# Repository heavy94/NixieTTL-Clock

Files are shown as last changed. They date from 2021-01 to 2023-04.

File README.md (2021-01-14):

# NixieTTL Clock
Tabletop digital clock built using TTL/CMOS logic ICs with a Nixie tube display.

**TODO**
- PCB layout and design.
- Test High Voltage power supply.
- Test need for base resistor on the cathode drivers.
- Test and tune blanking time generator.

**References**

This design is inspired by the following projects and resources:
- https://0x7d.com/2017/nixie-tube-clock/
- https://threeneurons.wordpress.com/nixie-power-supply/nixie-clock-kit-microcontroller/
- https://threeneurons.wordpress.com/nixie-power-supply/nixie-clock-kit-microcontroller/ghosting-due-to-transients/
- https://threeneurons.wordpress.com/nixie-power-supply/hv-supply-kit/

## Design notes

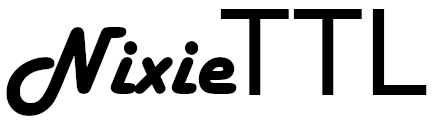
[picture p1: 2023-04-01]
NixieTTL.png

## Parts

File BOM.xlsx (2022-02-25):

Item | Qty | Reference(s) | Value | RS Reference | Mouser Reference | Datasheet
2 | 7 | C2, C3, C4, C5, C6, C7, C34 | 10n |  | 80-MMK5103J63J01TR18 | ~
3 | 19 | C8, C9, C10, C11, C12, C13, C14, C15, C16, C17, C18, C19, C20, C21, C22, C23, C24, C25, C26 | 100n |  | 80-R82DC3100AA50K | ~
4 | 2 | C27, C28 | 22p |  | 810-CC45SL3DD220JYGN | ~
5 | 1 | C29 | 22n |  |  | ~
6 | 1 | C30 | 10u 25V |  | 710-860020472003 (https://www.mouser.es/ProductDetail/710-860020472003) | ~
7 | 1 | C31 | 1u 16V |  | 710-860020672005 | ~
8 | 1 | C32 | 220u 25V |  | 710-860020474012 | ~
9 | 1 | C33 | 680p |  | 80-PFR5681J63J11L4 (https://www.mouser.es/ProductDetail/80-PFR5681J63J11L4) | ~
10 | 1 | C1, C35 | 3u3 250V |  | 710-860131174003 | ~
11 | 1 | D1 | 1N4001 |  | 625-1N4001-E3/54 | http://www.vishay.com/docs/88503/1n4001.pdf
12 | 1 | D2 | 1N914 |  | 78-1N914 | http://www.vishay.com/docs/85622/1n914.pdf
13 | 1 | D3 | MUR140 |  | 863-MUR140G | ~
14 | 1 | F1 | Fusible Clip |  | 693-0751.0062 | ~
15 | 2 | J1, J3 | Conn_02x02_Counter_Clockwise |  |  | https://www.mouser.es/Molex/Connectors/Headers-Wire-Housings/_/N-ay0loZ1yzvvqx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
16 | 2 | J2, J4 | Conn_02x09_Counter_Clockwise |  |  | ~
17 | 1 | J5 | Barrel_Jack |  | 163-179PH-EX | ~
18 | 1 | L1 | 560u 0,92A |  | 994-RFC1010B-564KE | ~
22 | 18 | Q1, Q2, Q3, Q4, Q5, Q6, Q7, Q8, Q9, Q10, Q11, Q12, Q15, Q16, Q17, Q18, Q21, Q22 | MPSA42 |  | 512-MPSA42 | http://www.onsemi.com/pub_link/Collateral/MPSA42-D.PDF
23 | 6 | Q13, Q14, Q19, Q20, Q23, Q24 | KSP92BU |  | 512-KSP92BU | http://www.onsemi.com/pub_link/Collateral/MPSA92-D.PDF
24 | 1 | Q25 | KSP2907A |  | 512-KSP2907ABU | ~
25 | 1 | Q26 | IRF644 |  | 844-IRF644PBF | ~
26 | 1 | R1 | 30k |  | 594-MBA0204BC3002FCT (https://www.mouser.es/ProductDetail/594-MBA0204BC3002FCT) | ~
28 | 25 | R2, R3, R4, R8, R9, R13, R14, R19, R20, R22, R24, R27, R28, R29, R30, R36, R38, R39, R40, R43, R45, R47, R48, R49, R50 | 220k |  | 603-MFR-25FTE52-220K | ~
29 | 11 | R5, R6, R10, R11, R15, R16, R25, R26, R31, R32, R59 | 1k24 1% |  | 603-MFR-25FBF52-1K24 | ~
30 | 12 | R7, R12, R17, R18, R33, R34, R41, R42, R53, R54, R55, R56 | 11k 1% |  | 603-MFR-25FBF52-11K | ~
33 | 1 | R51 | 4M7 |  | 594-VR25000004704JA1 | ~
34 | 1 | R52 | 20k |  |  | ~
35 | 2 | R57, R58 | 1.69 |  | 603-MFR-25FRF52-1R69 | ~
37 | 1 | R60 | 681k 1% |  | 603-MFR-25FBF52-681K (https://www.mouser.es/ProductDetail/603-MFR-25FBF52-681K) | ~
38 | 7 | R21, R23, R35, R37, R44, R46, R61 | 4k42 1% |  | 603-MFR-25FBF52-4K42 | ~
39 | 3 | SW1, SW2, SW3 | SW_Push |  | 642-MJTP1236D | ~
40 | 1 | SW4 | PB400EEQX |  | 612-PB400EEQX | ~
41 | 1 | U1 | 74LS14 | 14 | 595-SN74LS14N | http://www.ti.com/lit/gpn/sn74LS14
42 | 1 | U2 | 74LS109 | 16 | 595-SN74LS109AN | http://www.ti.com/lit/gpn/sn74LS109
43 | 1 | U3 | 74LS10 | 14 | 595-SN74LS10N | http://www.ti.com/lit/gpn/sn74LS10
44 | 2 | U4, U8 | 74LS08 | 14 | 595-SN74LS08N | http://www.ti.com/lit/gpn/sn74LS08
45 | 1 | U5 | 74LS393 | 14 | 595-SN74LS393N | 74xx\74LS393.pdf
46 | 1 | U6 | 74LS20 | 14 | 595-SN74LS20N | http://www.ti.com/lit/gpn/sn74LS20
47 | 1 | U7 | 74HC4060 | 16 | 595-SN74HC4060N | http://www.ti.com/lit/ds/symlink/dac5311.pdf
48 | 2 | U9, U13 | 4028 | 16 | 595-CD4028BE | http://www.intersil.com/content/dam/Intersil/documents/cd40/cd4028bms.pdf
49 | 4 | U10, U11, U12, U14 | 74LS151 | 16 | 595-SN74LS151N | http://www.ti.com/lit/gpn/sn74LS151
50 | 6 | U15, U16, U17, U18, U19, U20 | 74LS160 | 16 |  | http://www.ti.com/lit/gpn/sn74LS160
51 | 1 | U21 | L7805 |  | 511-L7805CV | http://www.st.com/content/ccc/resource/technical/document/datasheet/41/4f/b3/b0/12/d4/47/88/CD00000444.pdf/files/CD00000444.pdf/jcr:content/translations/en.CD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
52 | 1 | U22 | MC34063AP |  | 595-MC34063AP | http://www.onsemi.com/pub_link/Collateral/MC34063A-D.PDF
53 | 1 | Y1 | 32.768 kHz - 12.5pF |  | 449-LFXTAL002996BULK | ~
54 | 6 | Zocalo DIP14 |  |  | 649-DILB14P-223TLF
55 | 14 | Zocalo DIP16 |  |  | 649-DILB16P-223TLF

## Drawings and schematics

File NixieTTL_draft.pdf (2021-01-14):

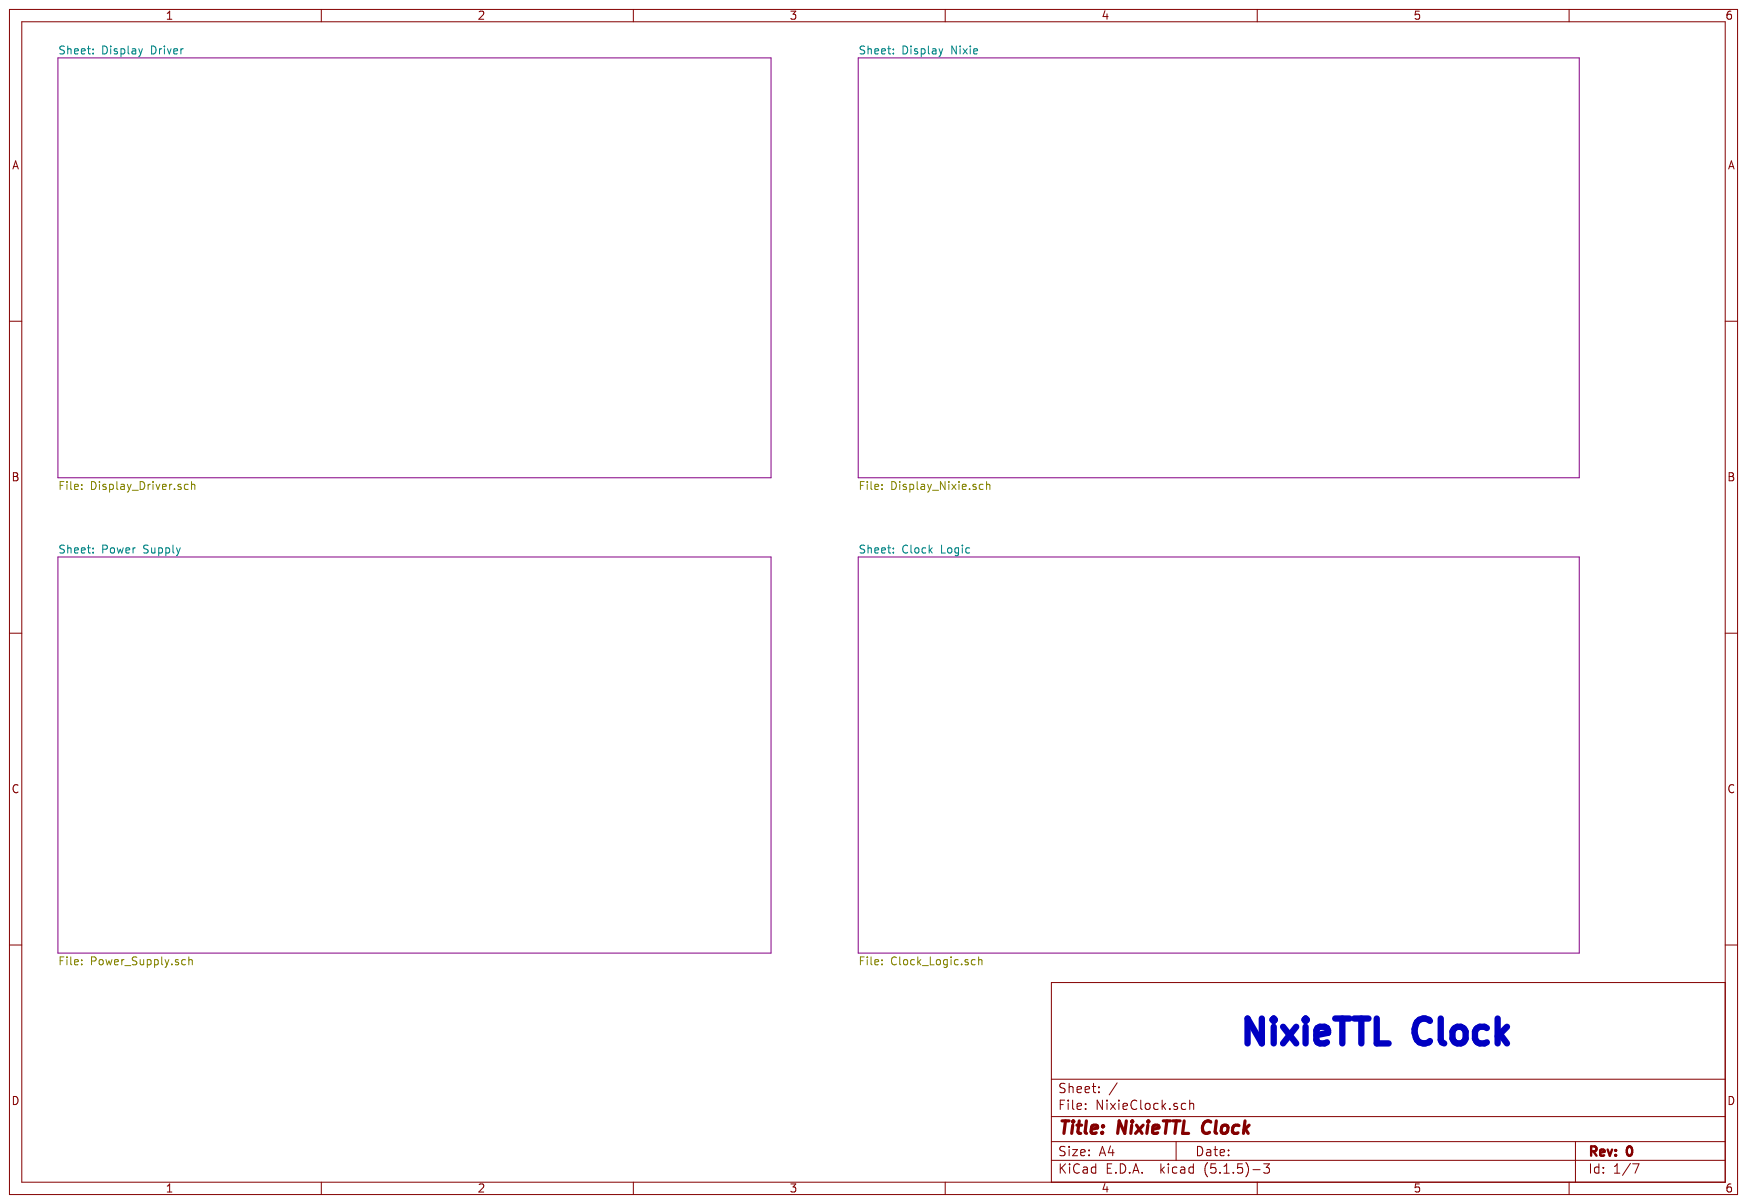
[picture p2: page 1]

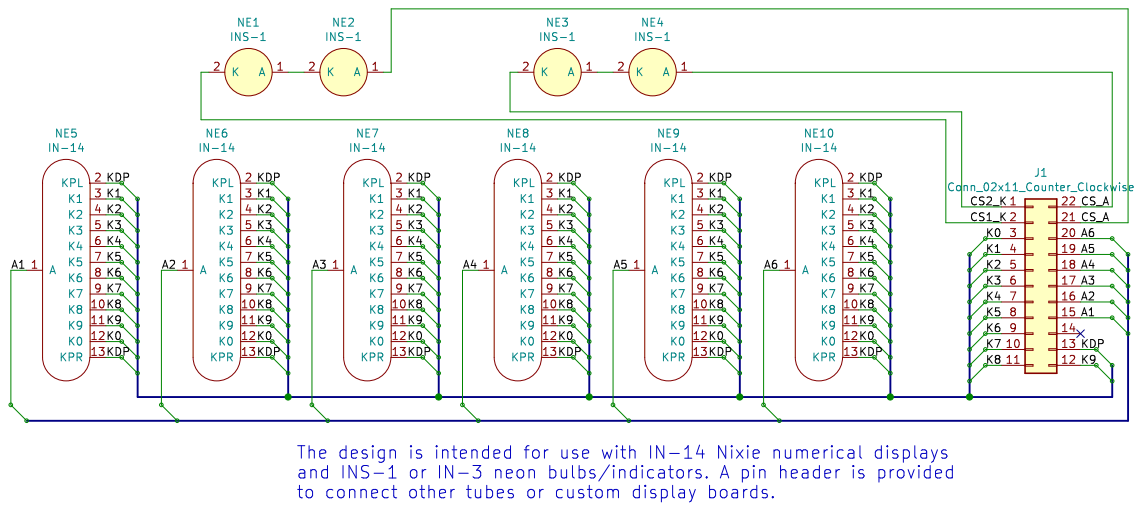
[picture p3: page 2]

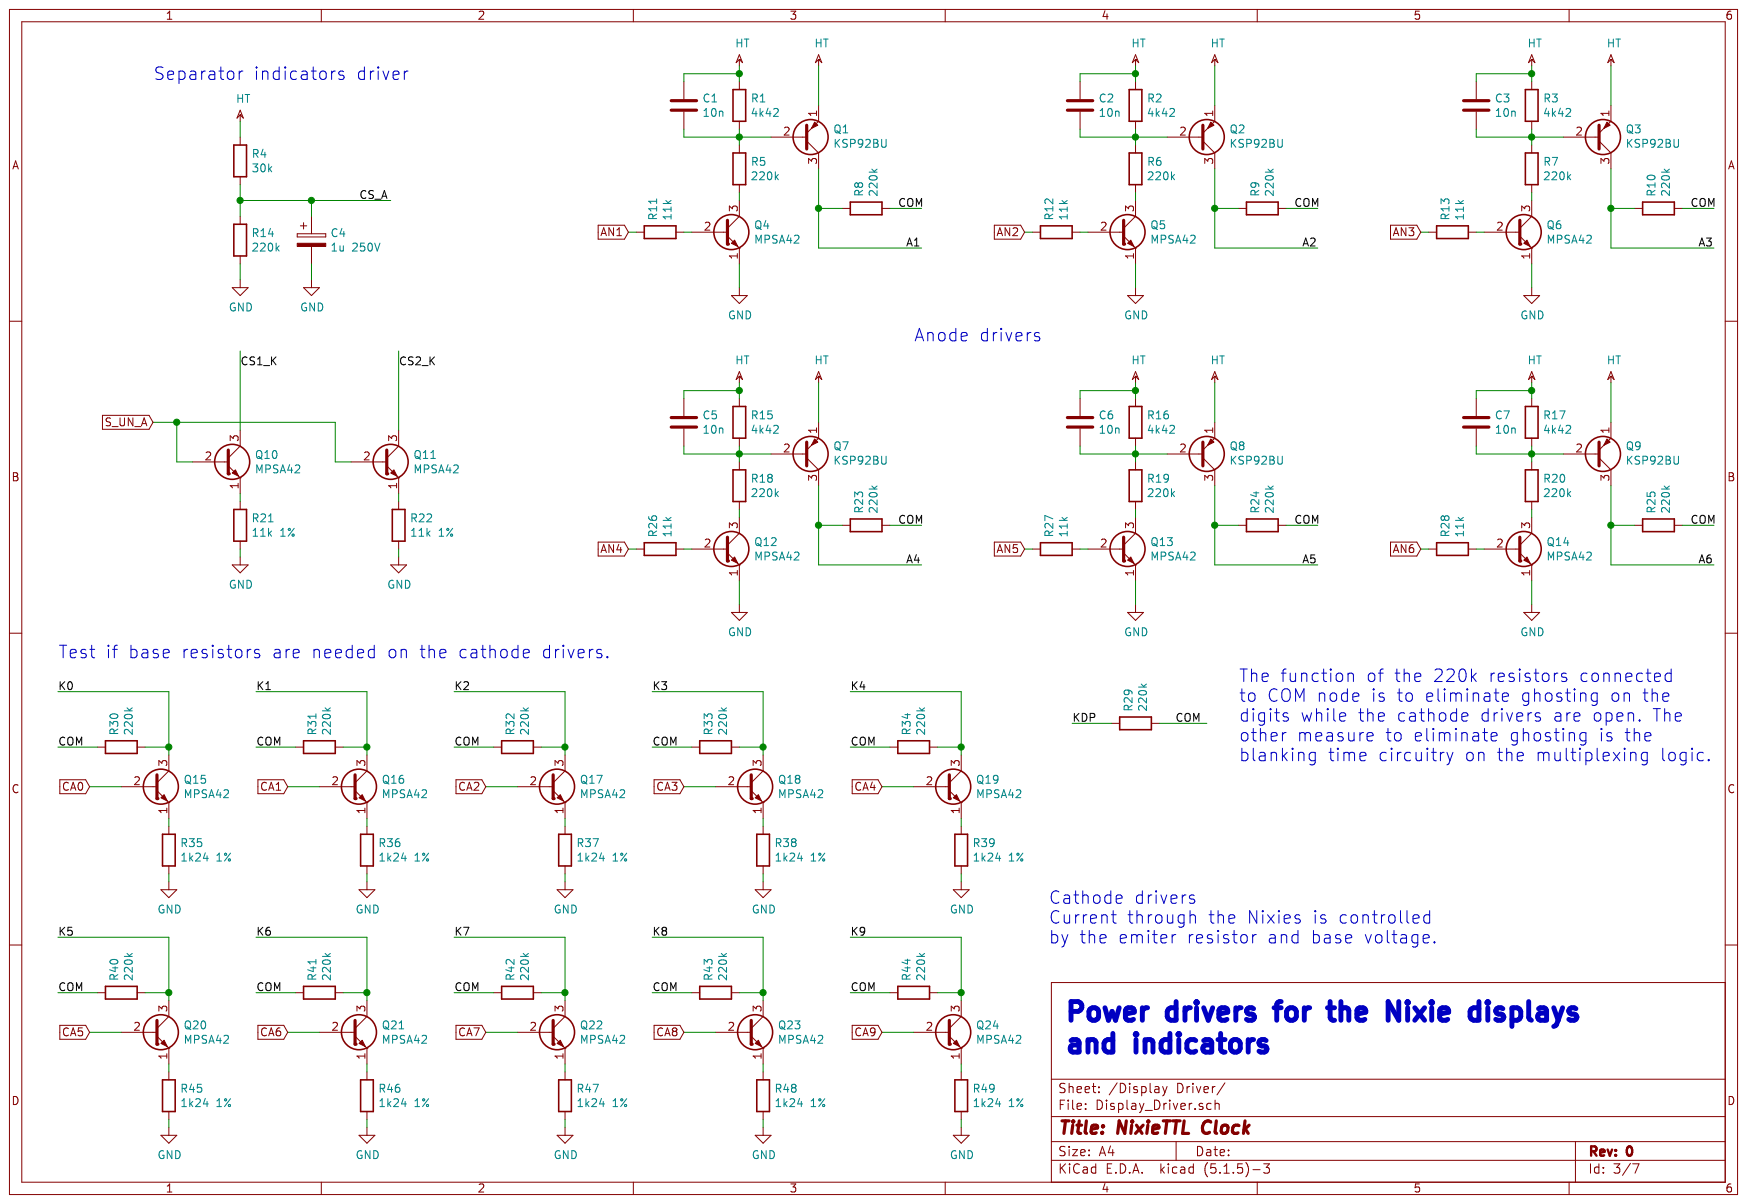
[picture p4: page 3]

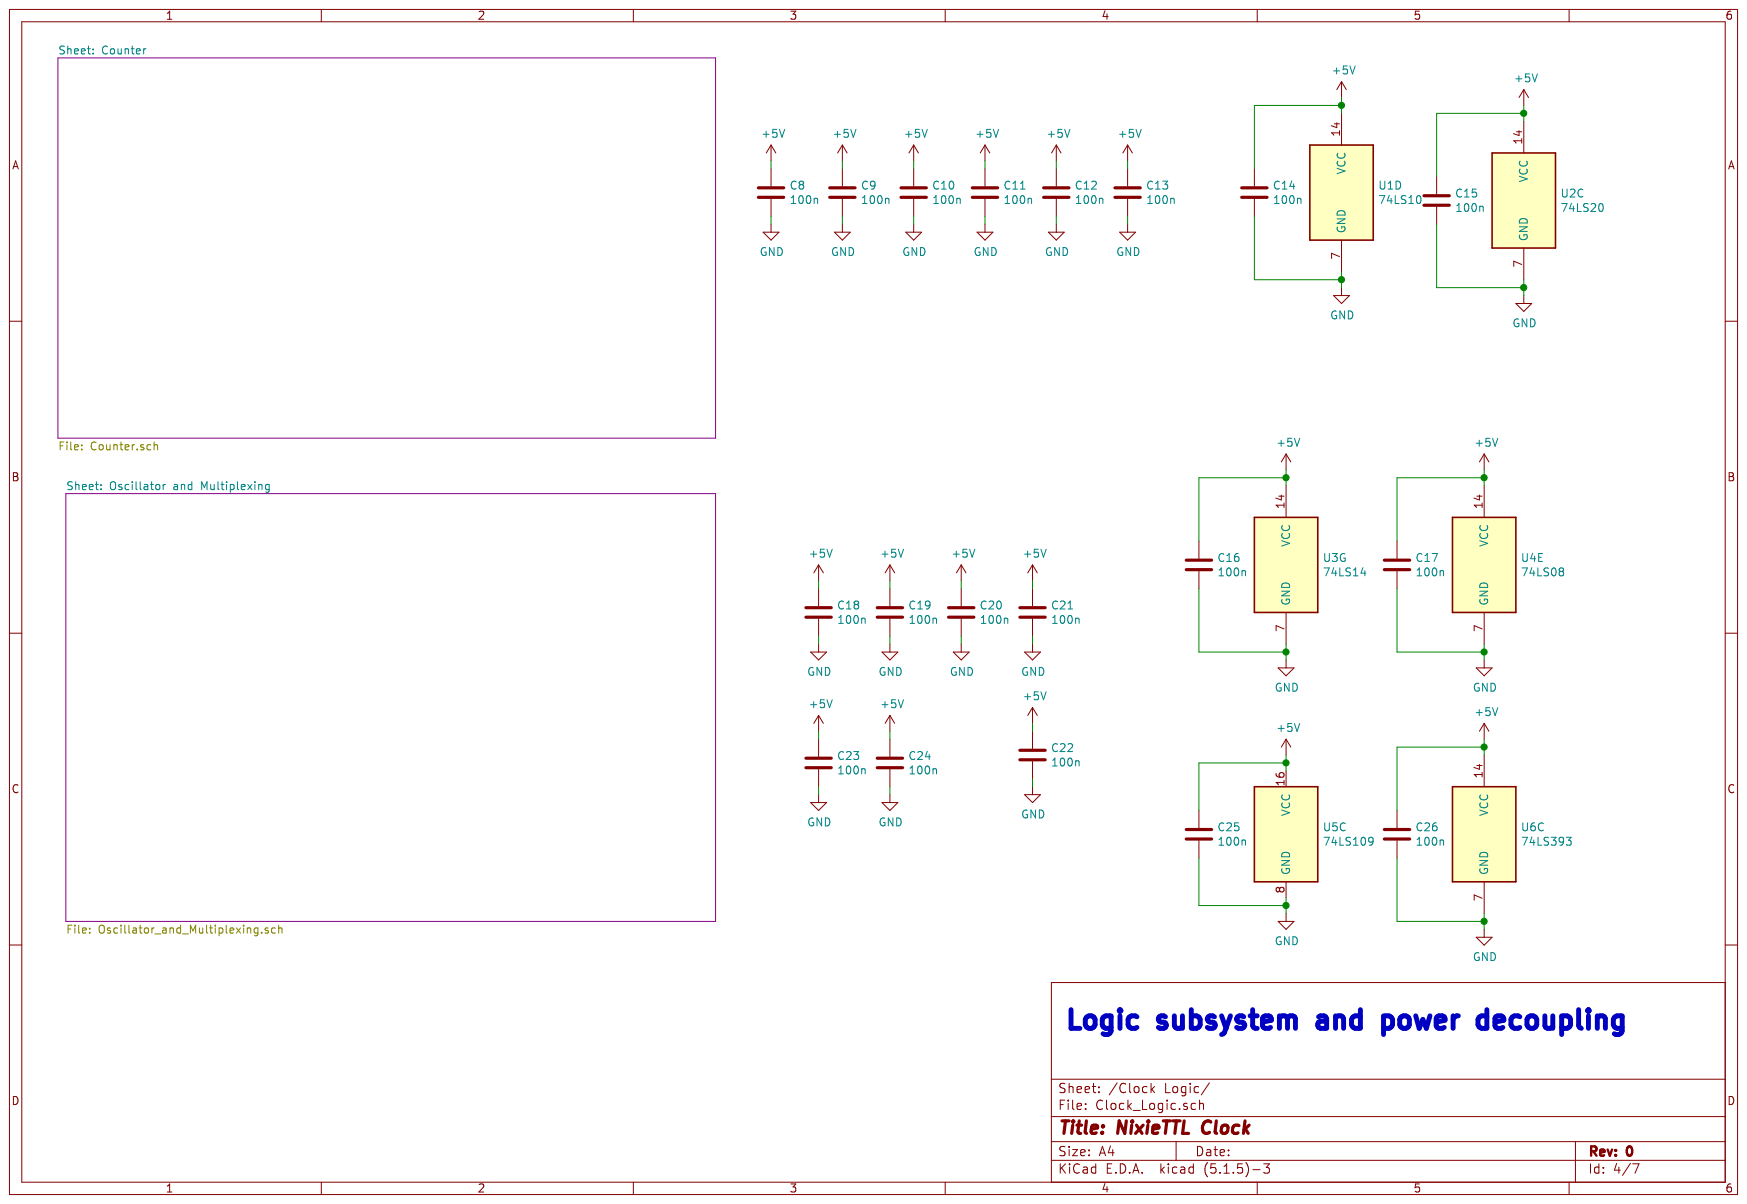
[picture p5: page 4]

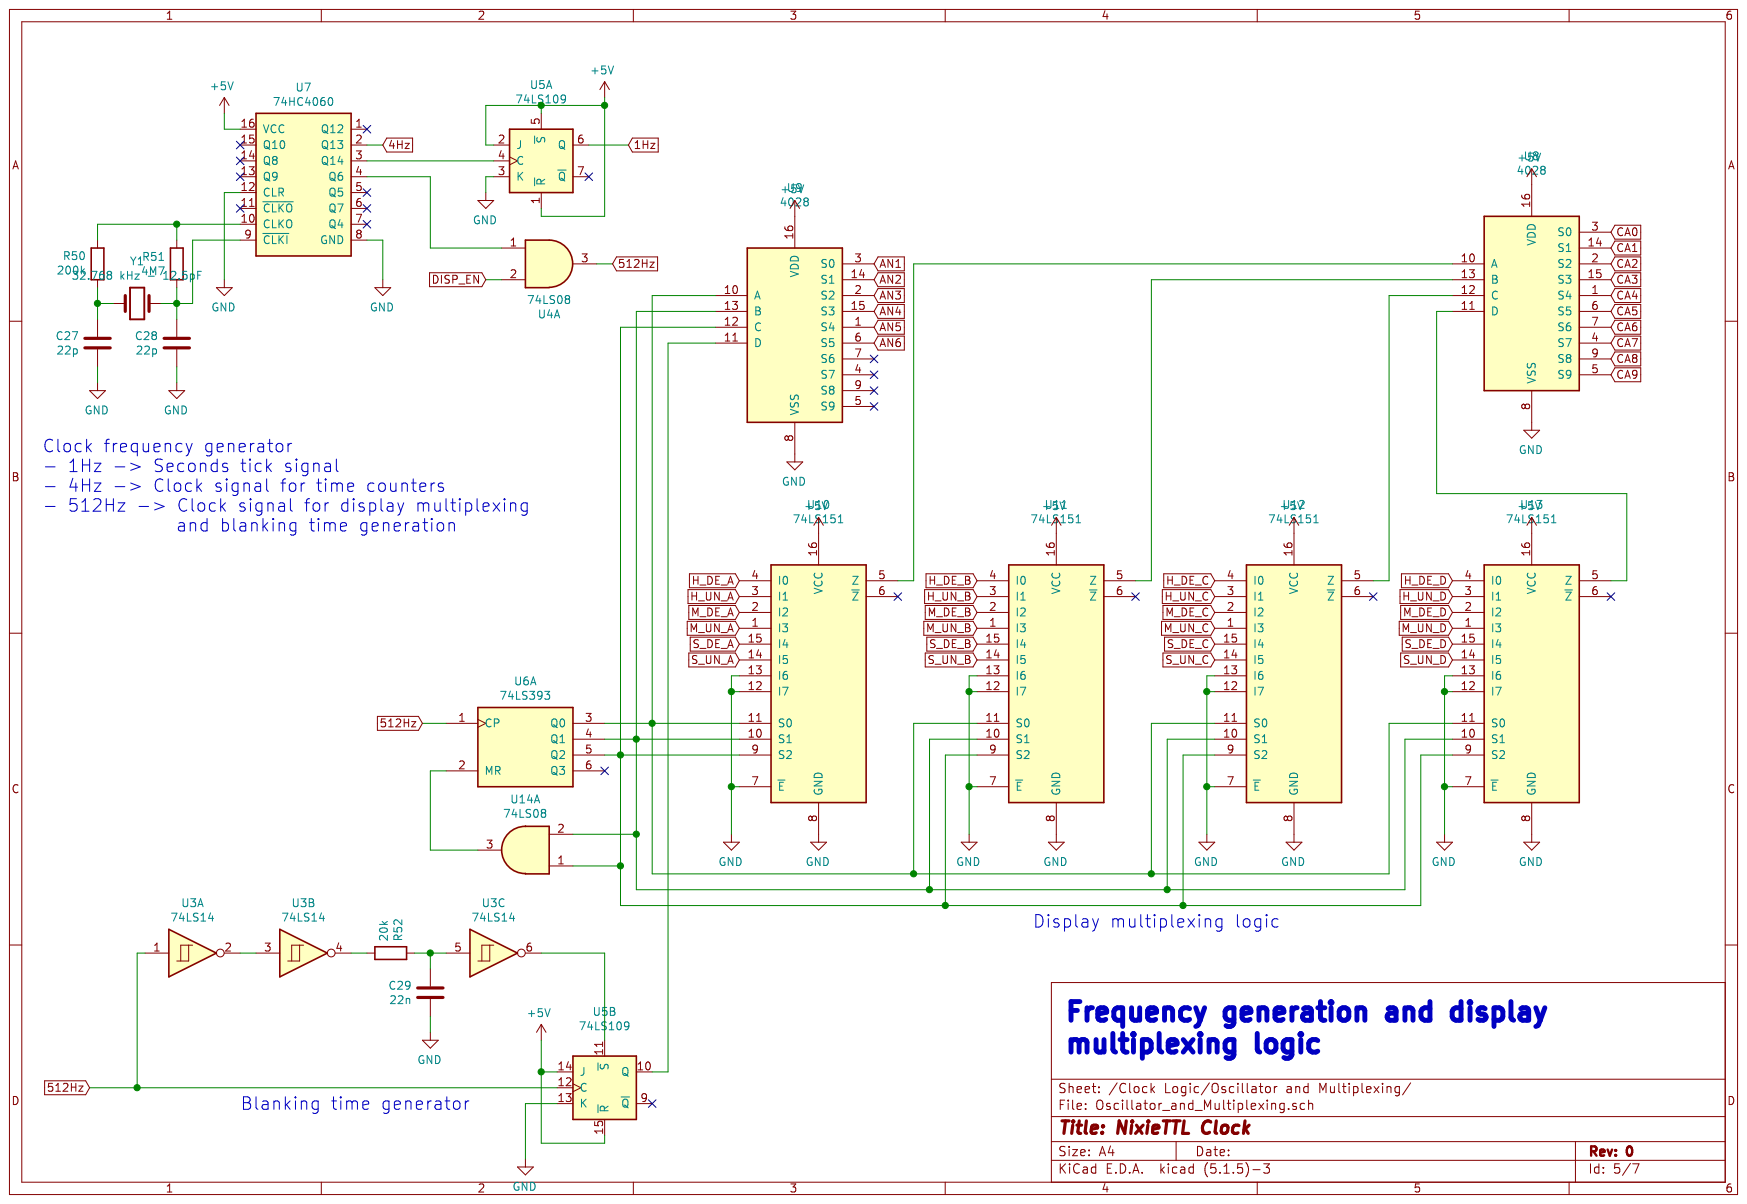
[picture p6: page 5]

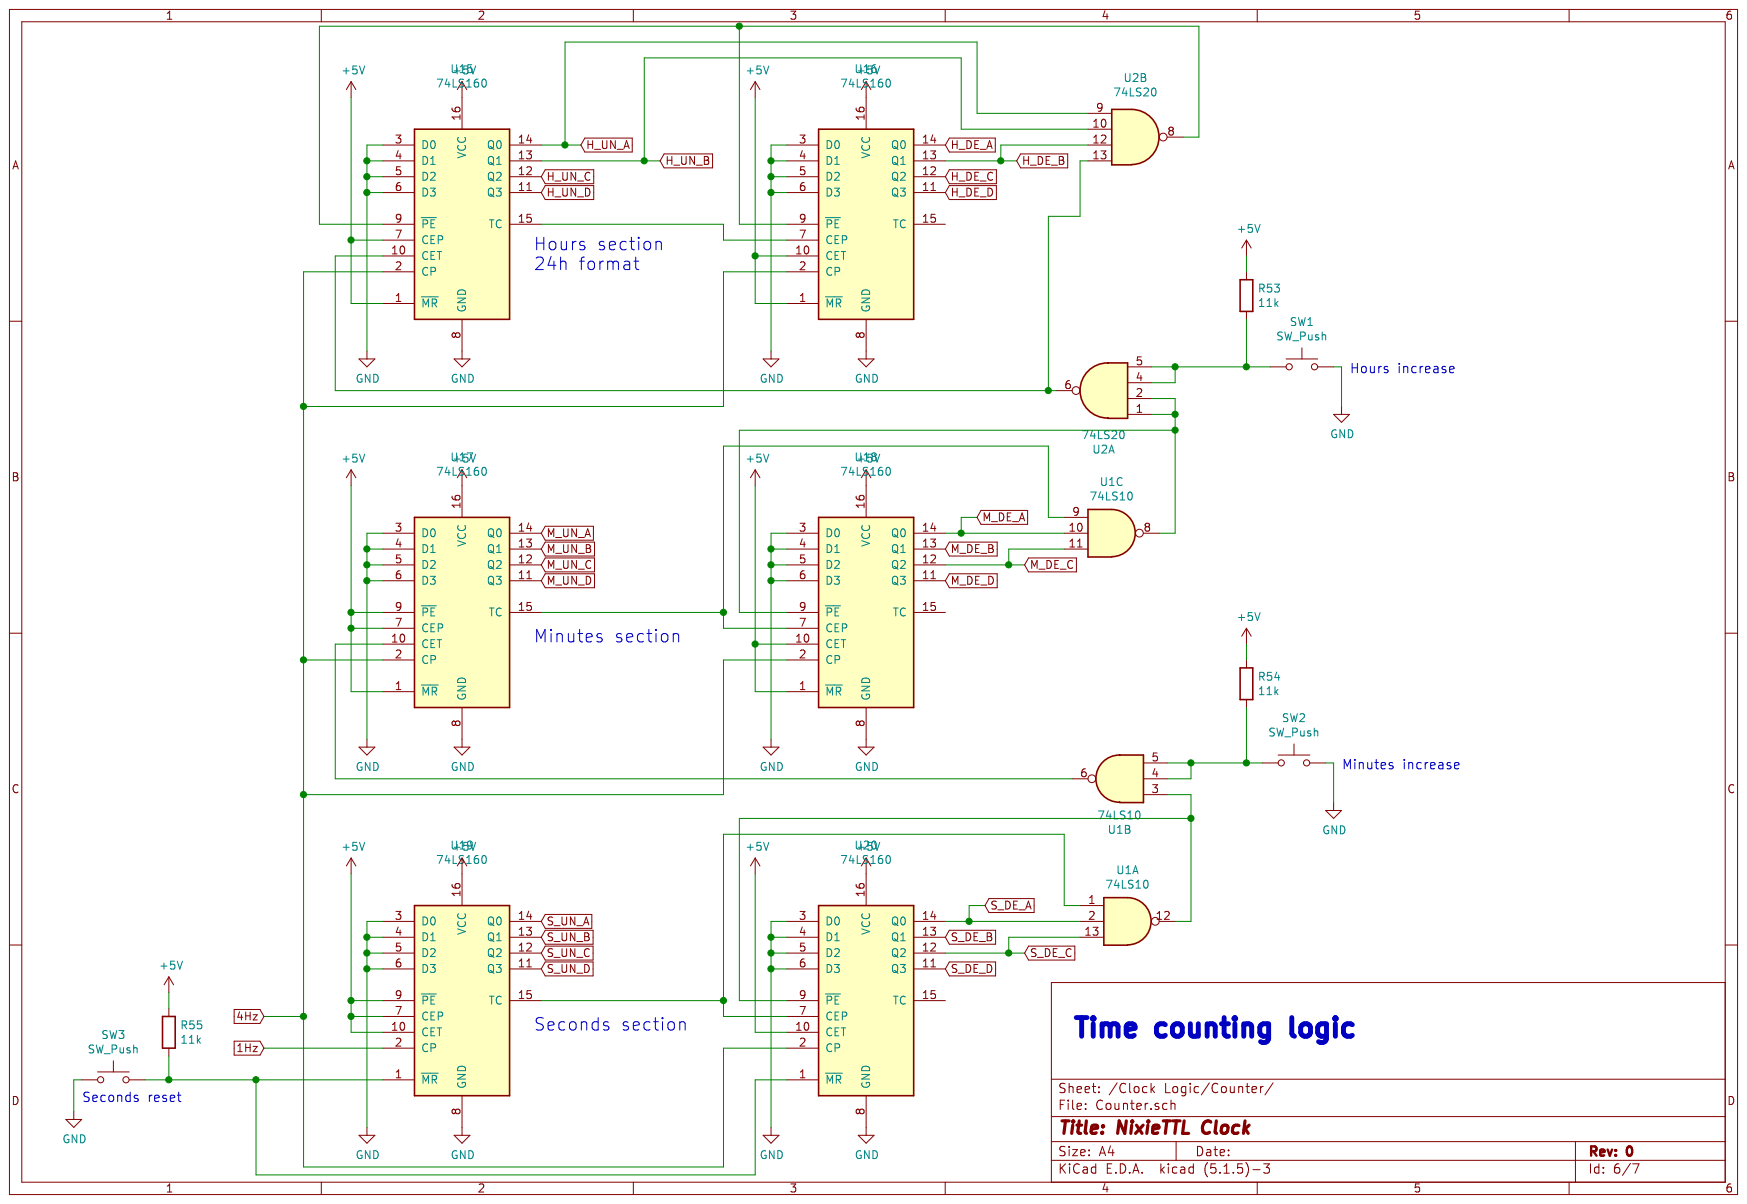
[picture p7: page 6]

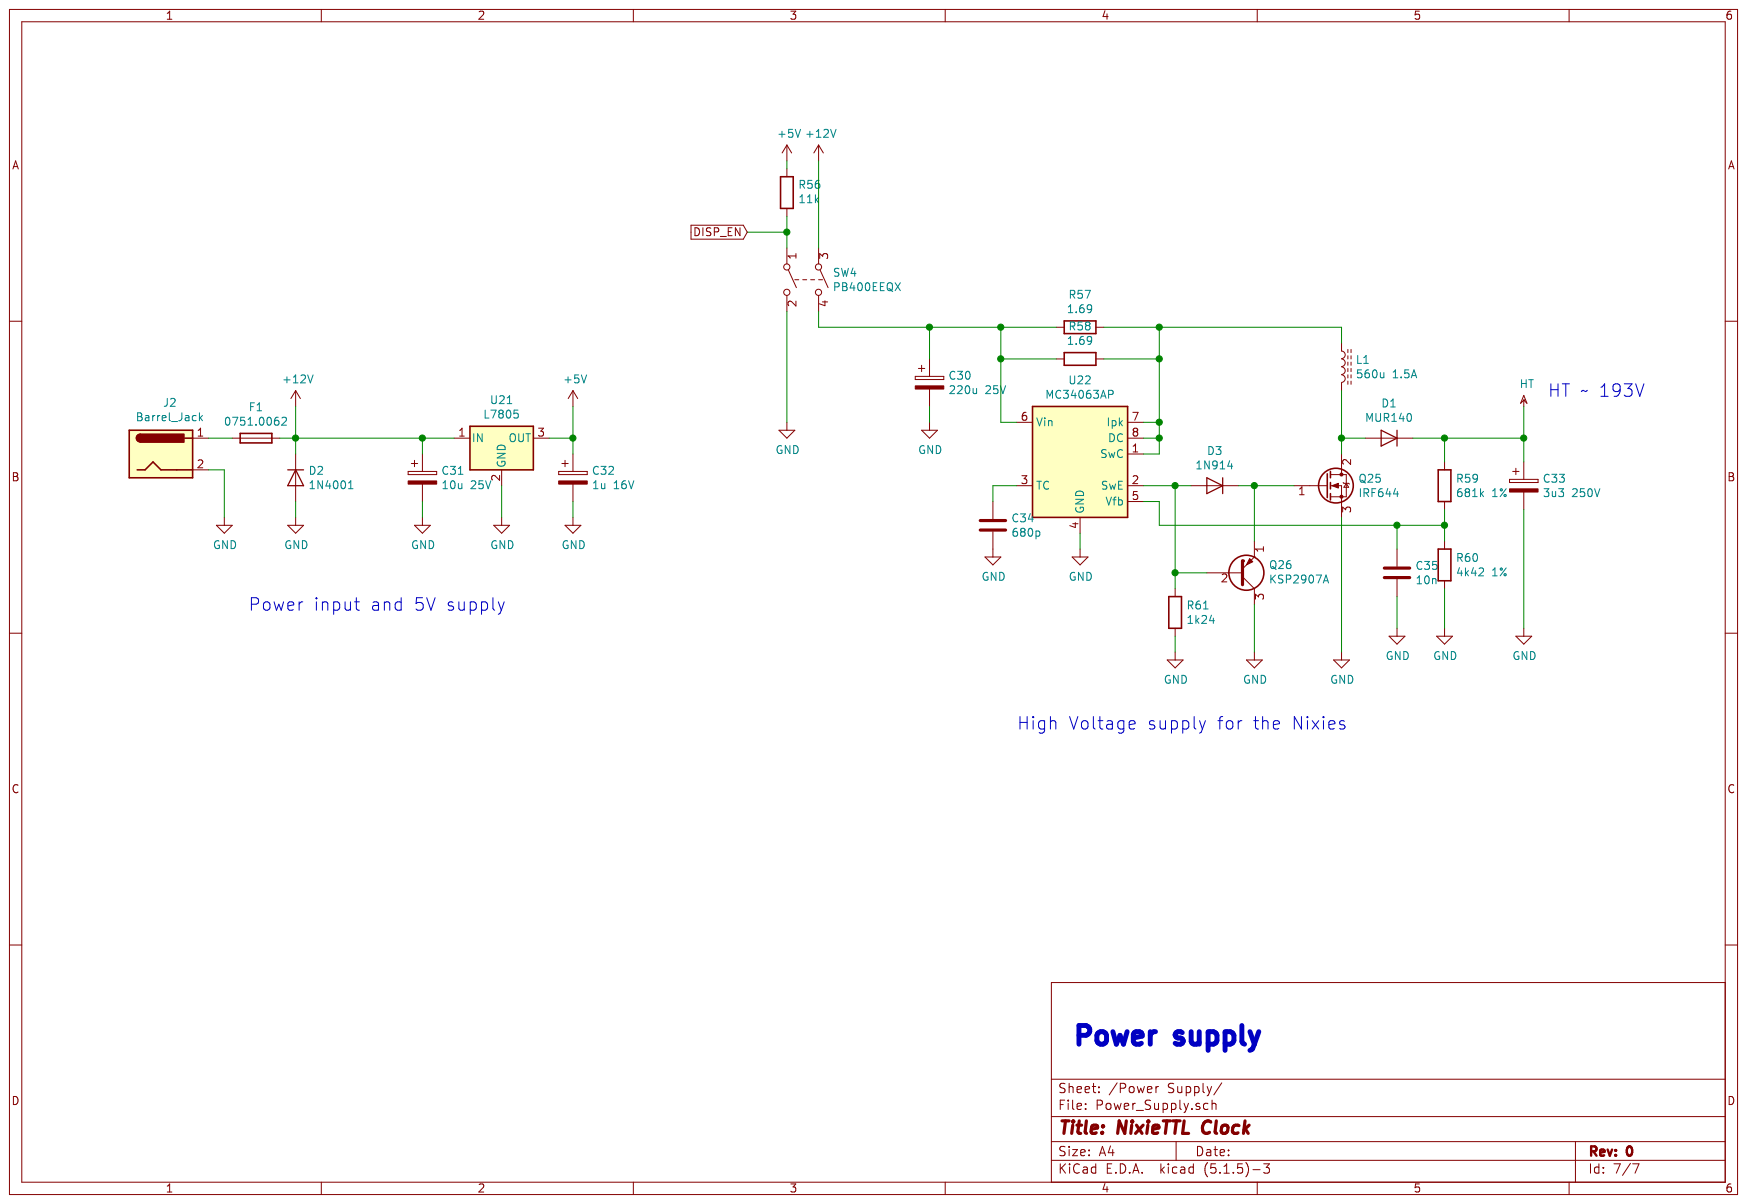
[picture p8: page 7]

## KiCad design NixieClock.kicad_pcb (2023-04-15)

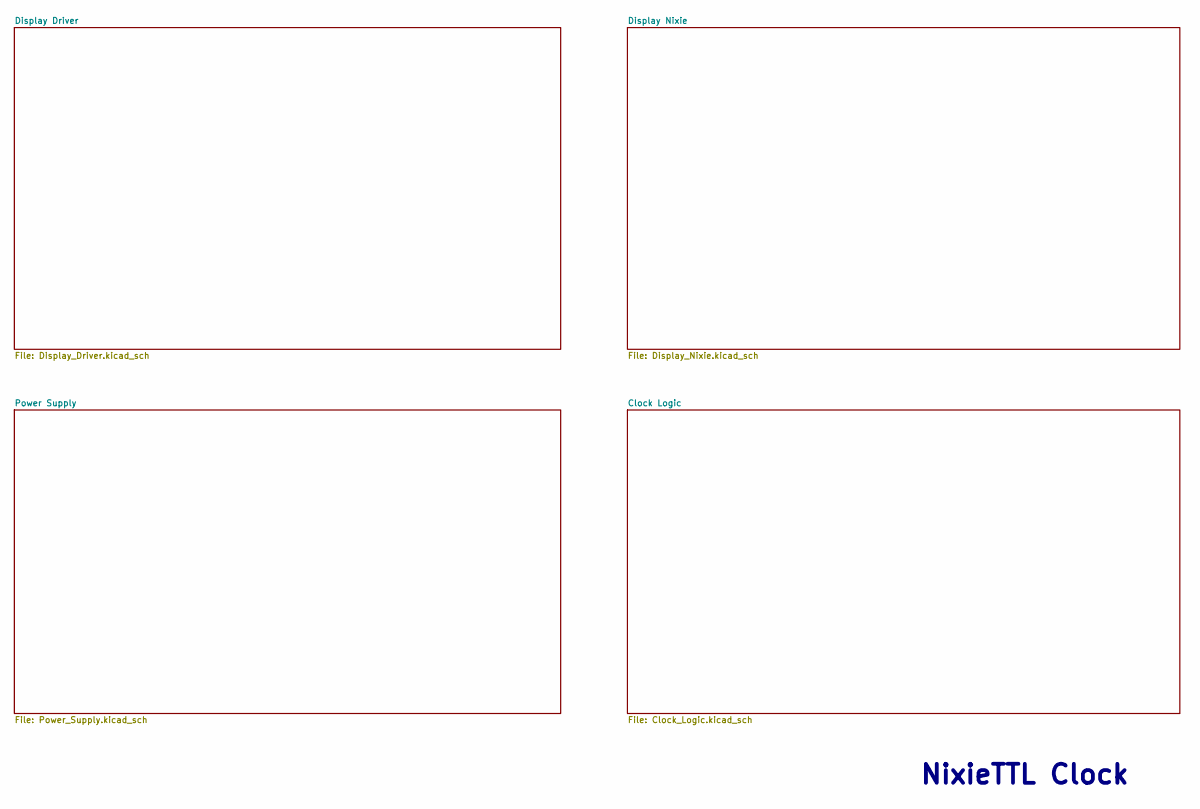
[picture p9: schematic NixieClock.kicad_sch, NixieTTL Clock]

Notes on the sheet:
NixieTTL Clock

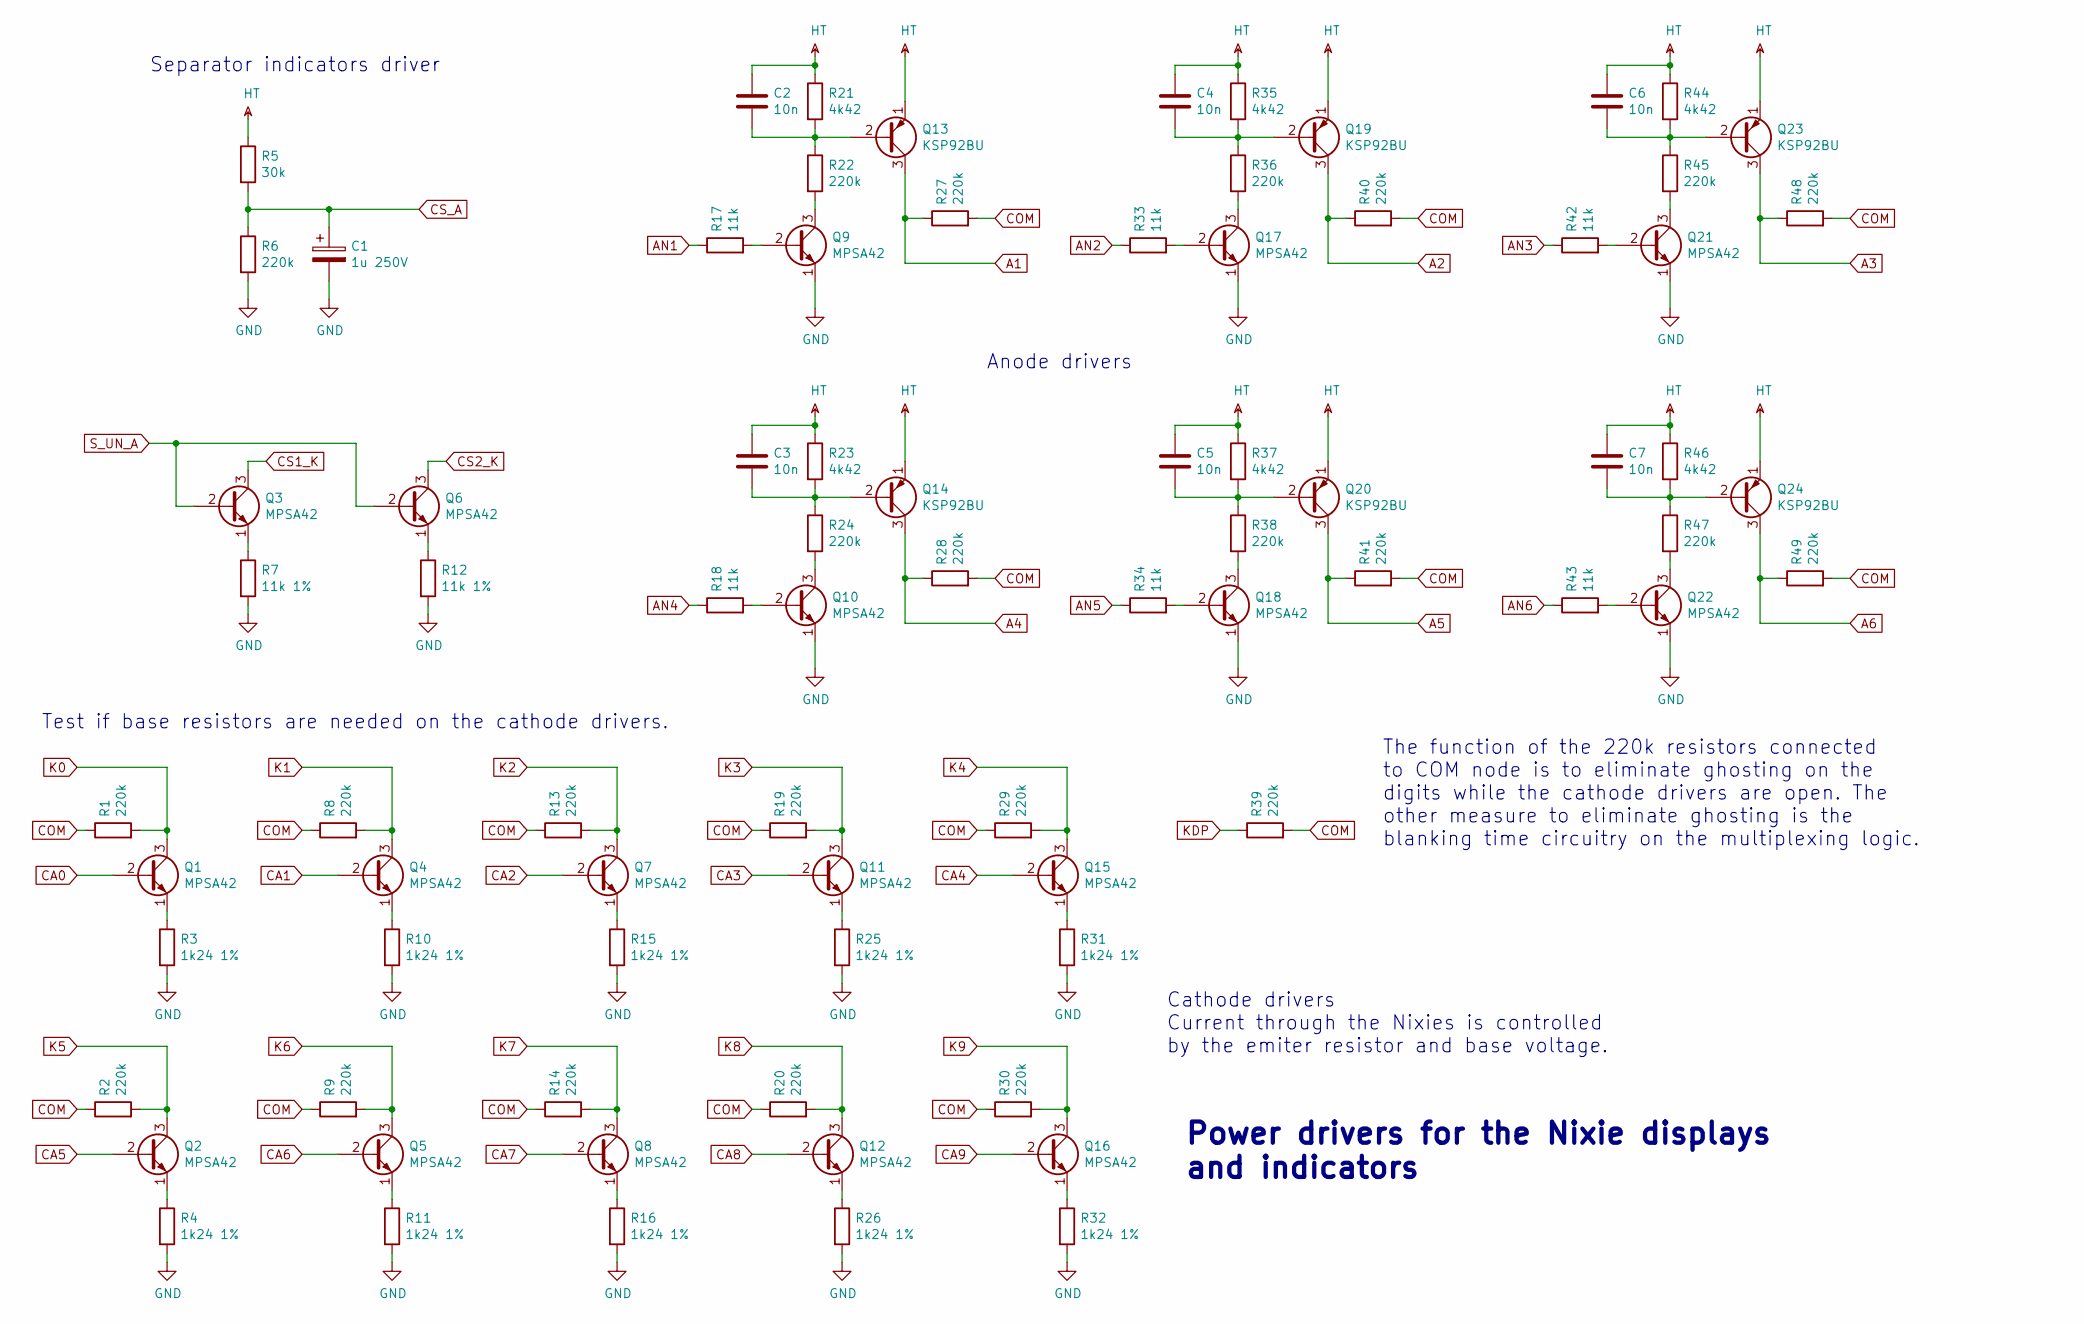
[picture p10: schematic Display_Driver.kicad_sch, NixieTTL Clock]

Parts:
C1: 1u 250V; CP_Radial_D8.0mm_P3.80mm
C2, C3, C4, C5, C6, C7: 10n; C_Rect_L7.0mm_W2.5mm_P5.00mm
Q1, Q2, Q3, Q4, Q5, Q6, Q7, Q8, Q9, Q10, Q11, Q12, Q15, Q16, Q17, Q18, Q21, Q22: MPSA42; TO-92_Inline_Wide
Q13, Q14, Q19, Q20, Q23, Q24: KSP92BU; TO-92_Inline_Wide
R1, R2, R6, R8, R9, R13, R14, R19, R20, R22, R24, R27, R28, R29, R30, R36, R38, R39, R40, R41, R45, R47, R48, R49: 220k; R_Axial_DIN0207_L6.3mm_D2.5mm_P10.16mm_Horizontal
R3, R4, R10, R11, R15, R16, R25, R26, R31, R32: 1k24 1%; R_Axial_DIN0207_L6.3mm_D2.5mm_P10.16mm_Horizontal
R5: 30k; R_Axial_DIN0207_L6.3mm_D2.5mm_P10.16mm_Horizontal
R7, R12: 11k 1%; R_Axial_DIN0207_L6.3mm_D2.5mm_P10.16mm_Horizontal
R17, R18, R33, R34, R42, R43: 11k; R_Axial_DIN0207_L6.3mm_D2.5mm_P10.16mm_Horizontal
R21, R23, R35, R37, R44, R46: 4k42; R_Axial_DIN0207_L6.3mm_D2.5mm_P10.16mm_Horizontal

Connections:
A1: Q13.3 (C), R27.1; also elsewhere on the board
A2: Q19.3 (C), R40.1; also elsewhere on the board
A3: Q23.3 (C), R48.1; also elsewhere on the board
A4: Q14.3 (C), R28.1; also elsewhere on the board
A5: Q20.3 (C), R41.1; also elsewhere on the board
A6: Q24.3 (C), R49.1; also elsewhere on the board
AN1: R17.1; also elsewhere on the board
AN2: R33.1; also elsewhere on the board
AN3: R42.1; also elsewhere on the board
AN4: R18.1; also elsewhere on the board
AN5: R34.1; also elsewhere on the board
AN6: R43.1; also elsewhere on the board
CA0: Q1.2 (B); also elsewhere on the board
CA1: Q4.2 (B); also elsewhere on the board
CA2: Q7.2 (B); also elsewhere on the board
CA3: Q11.2 (B); also elsewhere on the board
CA4: Q15.2 (B); also elsewhere on the board
CA5: Q2.2 (B); also elsewhere on the board
CA6: Q5.2 (B); also elsewhere on the board
CA7: Q8.2 (B); also elsewhere on the board
CA8: Q12.2 (B); also elsewhere on the board
CA9: Q16.2 (B); also elsewhere on the board
COM: R1.1, R2.1, R8.1, R9.1, R13.1, R14.1, R19.1, R20.1, R27.2, R28.2, R29.1, R30.1, R39.2, R40.2, R41.2, R48.2, R49.2
CS1_K: Q3.3 (C); also elsewhere on the board
CS2_K: Q6.3 (C); also elsewhere on the board
CS_A: C1.1, R5.2, R6.1; also elsewhere on the board
GND: C1.2, Q9.1 (E), Q10.1 (E), Q17.1 (E), Q18.1 (E), Q21.1 (E), Q22.1 (E), R3.2, R4.2, R6.2, R7.2, R10.2, R11.2, R12.2, R15.2, R16.2, R25.2, R26.2, R31.2, R32.2; also elsewhere on the board
HT: C2.1, C3.1, C4.1, C5.1, C6.1, C7.1, Q13.1 (E), Q14.1 (E), Q19.1 (E), Q20.1 (E), Q23.1 (E), Q24.1 (E), R5.1, R21.1, R23.1, R35.1, R37.1, R44.1, R46.1; also elsewhere on the board
K0: Q1.3 (C), R1.2; also elsewhere on the board
K1: Q4.3 (C), R8.2; also elsewhere on the board
K2: Q7.3 (C), R13.2; also elsewhere on the board
K3: Q11.3 (C), R19.2; also elsewhere on the board
K4: Q15.3 (C), R29.2; also elsewhere on the board
K5: Q2.3 (C), R2.2; also elsewhere on the board
K6: Q5.3 (C), R9.2; also elsewhere on the board
K7: Q8.3 (C), R14.2; also elsewhere on the board
K8: Q12.3 (C), R20.2; also elsewhere on the board
K9: Q16.3 (C), R30.2; also elsewhere on the board
KDP: R39.1; also elsewhere on the board
unnamed: C2.2, Q13.2 (B), R21.2, R22.1
unnamed: C3.2, Q14.2 (B), R23.2, R24.1
unnamed: C4.2, Q19.2 (B), R35.2, R36.1
unnamed: C5.2, Q20.2 (B), R37.2, R38.1
unnamed: C6.2, Q23.2 (B), R44.2, R45.1
unnamed: C7.2, Q24.2 (B), R46.2, R47.1
unnamed: Q1.1 (E), R3.1
unnamed: Q2.1 (E), R4.1
unnamed: Q3.1 (E), R7.1
unnamed: Q4.1 (E), R10.1
unnamed: Q5.1 (E), R11.1
unnamed: Q6.1 (E), R12.1
unnamed: Q7.1 (E), R15.1
unnamed: Q8.1 (E), R16.1
unnamed: Q9.2 (B), R17.2
unnamed: Q9.3 (C), R22.2
unnamed: Q10.2 (B), R18.2
unnamed: Q10.3 (C), R24.2
unnamed: Q11.1 (E), R25.1
unnamed: Q12.1 (E), R26.1
unnamed: Q15.1 (E), R31.1
unnamed: Q16.1 (E), R32.1
unnamed: Q17.2 (B), R33.2
unnamed: Q17.3 (C), R36.2
unnamed: Q18.2 (B), R34.2
unnamed: Q18.3 (C), R38.2
unnamed: Q21.2 (B), R42.2
unnamed: Q21.3 (C), R45.2
unnamed: Q22.2 (B), R43.2
unnamed: Q22.3 (C), R47.2
S_UN_A: Q3.2 (B), Q6.2 (B); also elsewhere on the board

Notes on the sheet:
Test if base resistors are needed on the cathode drivers.
The function of the 220k resistors connected to COM node is to eliminate ghosting on the digits while the cathode drivers are open. The other measure to eliminate ghosting is the blanking time circuitry on the multiplexing logic.
Separator indicators driver
Power drivers for the Nixie displays and indicators
Cathode drivers Current through the Nixies is controlled by the emiter resistor and base voltage.
Anode drivers

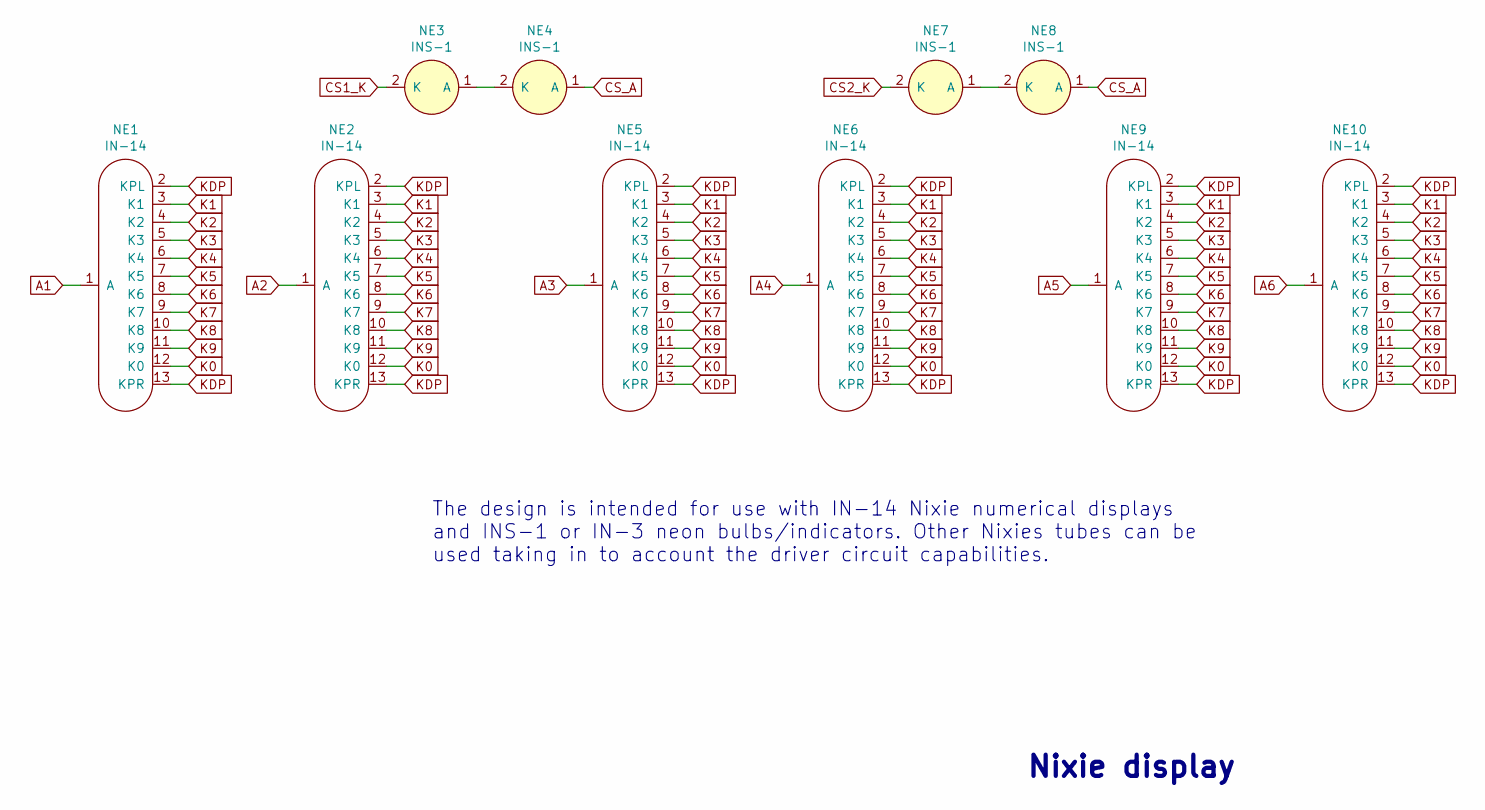
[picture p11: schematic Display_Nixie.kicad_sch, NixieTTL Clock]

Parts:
NE1, NE2, NE5, NE6, NE9, NE10: IN-14
NE3, NE4, NE7, NE8: INS-1; PinSocket_1x02_P2.54mm_Vertical

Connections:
A1: NE1.1 (A); also elsewhere on the board
A2: NE2.1 (A); also elsewhere on the board
A3: NE5.1 (A); also elsewhere on the board
A4: NE6.1 (A); also elsewhere on the board
A5: NE9.1 (A); also elsewhere on the board
A6: NE10.1 (A); also elsewhere on the board
CS1_K: NE3.2 (K); also elsewhere on the board
CS2_K: NE7.2 (K); also elsewhere on the board
CS_A: NE4.1 (A), NE8.1 (A); also elsewhere on the board
K0: NE1.12 (K0), NE2.12 (K0), NE5.12 (K0), NE6.12 (K0), NE9.12 (K0), NE10.12 (K0); also elsewhere on the board
K1: NE1.3 (K1), NE2.3 (K1), NE5.3 (K1), NE6.3 (K1), NE9.3 (K1), NE10.3 (K1); also elsewhere on the board
K2: NE1.4 (K2), NE2.4 (K2), NE5.4 (K2), NE6.4 (K2), NE9.4 (K2), NE10.4 (K2); also elsewhere on the board
K3: NE1.5 (K3), NE2.5 (K3), NE5.5 (K3), NE6.5 (K3), NE9.5 (K3), NE10.5 (K3); also elsewhere on the board
K4: NE1.6 (K4), NE2.6 (K4), NE5.6 (K4), NE6.6 (K4), NE9.6 (K4), NE10.6 (K4); also elsewhere on the board
K5: NE1.7 (K5), NE2.7 (K5), NE5.7 (K5), NE6.7 (K5), NE9.7 (K5), NE10.7 (K5); also elsewhere on the board
K6: NE1.8 (K6), NE2.8 (K6), NE5.8 (K6), NE6.8 (K6), NE9.8 (K6), NE10.8 (K6); also elsewhere on the board
K7: NE1.9 (K7), NE2.9 (K7), NE5.9 (K7), NE6.9 (K7), NE9.9 (K7), NE10.9 (K7); also elsewhere on the board
K8: NE1.10 (K8), NE2.10 (K8), NE5.10 (K8), NE6.10 (K8), NE9.10 (K8), NE10.10 (K8); also elsewhere on the board
K9: NE1.11 (K9), NE2.11 (K9), NE5.11 (K9), NE6.11 (K9), NE9.11 (K9), NE10.11 (K9); also elsewhere on the board
KDP: NE1.2 (KPL), NE1.13 (KPR), NE2.2 (KPL), NE2.13 (KPR), NE5.2 (KPL), NE5.13 (KPR), NE6.2 (KPL), NE6.13 (KPR), NE9.2 (KPL), NE9.13 (KPR), NE10.2 (KPL), NE10.13 (KPR); also elsewhere on the board
unnamed: NE3.1 (A), NE4.2 (K)
unnamed: NE7.1 (A), NE8.2 (K)

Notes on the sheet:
Nixie display
The design is intended for use with IN-14 Nixie numerical displays and INS-1 or IN-3 neon bulbs/indicators. Other Nixies tubes can be used taking in to account the driver circuit capabilities.

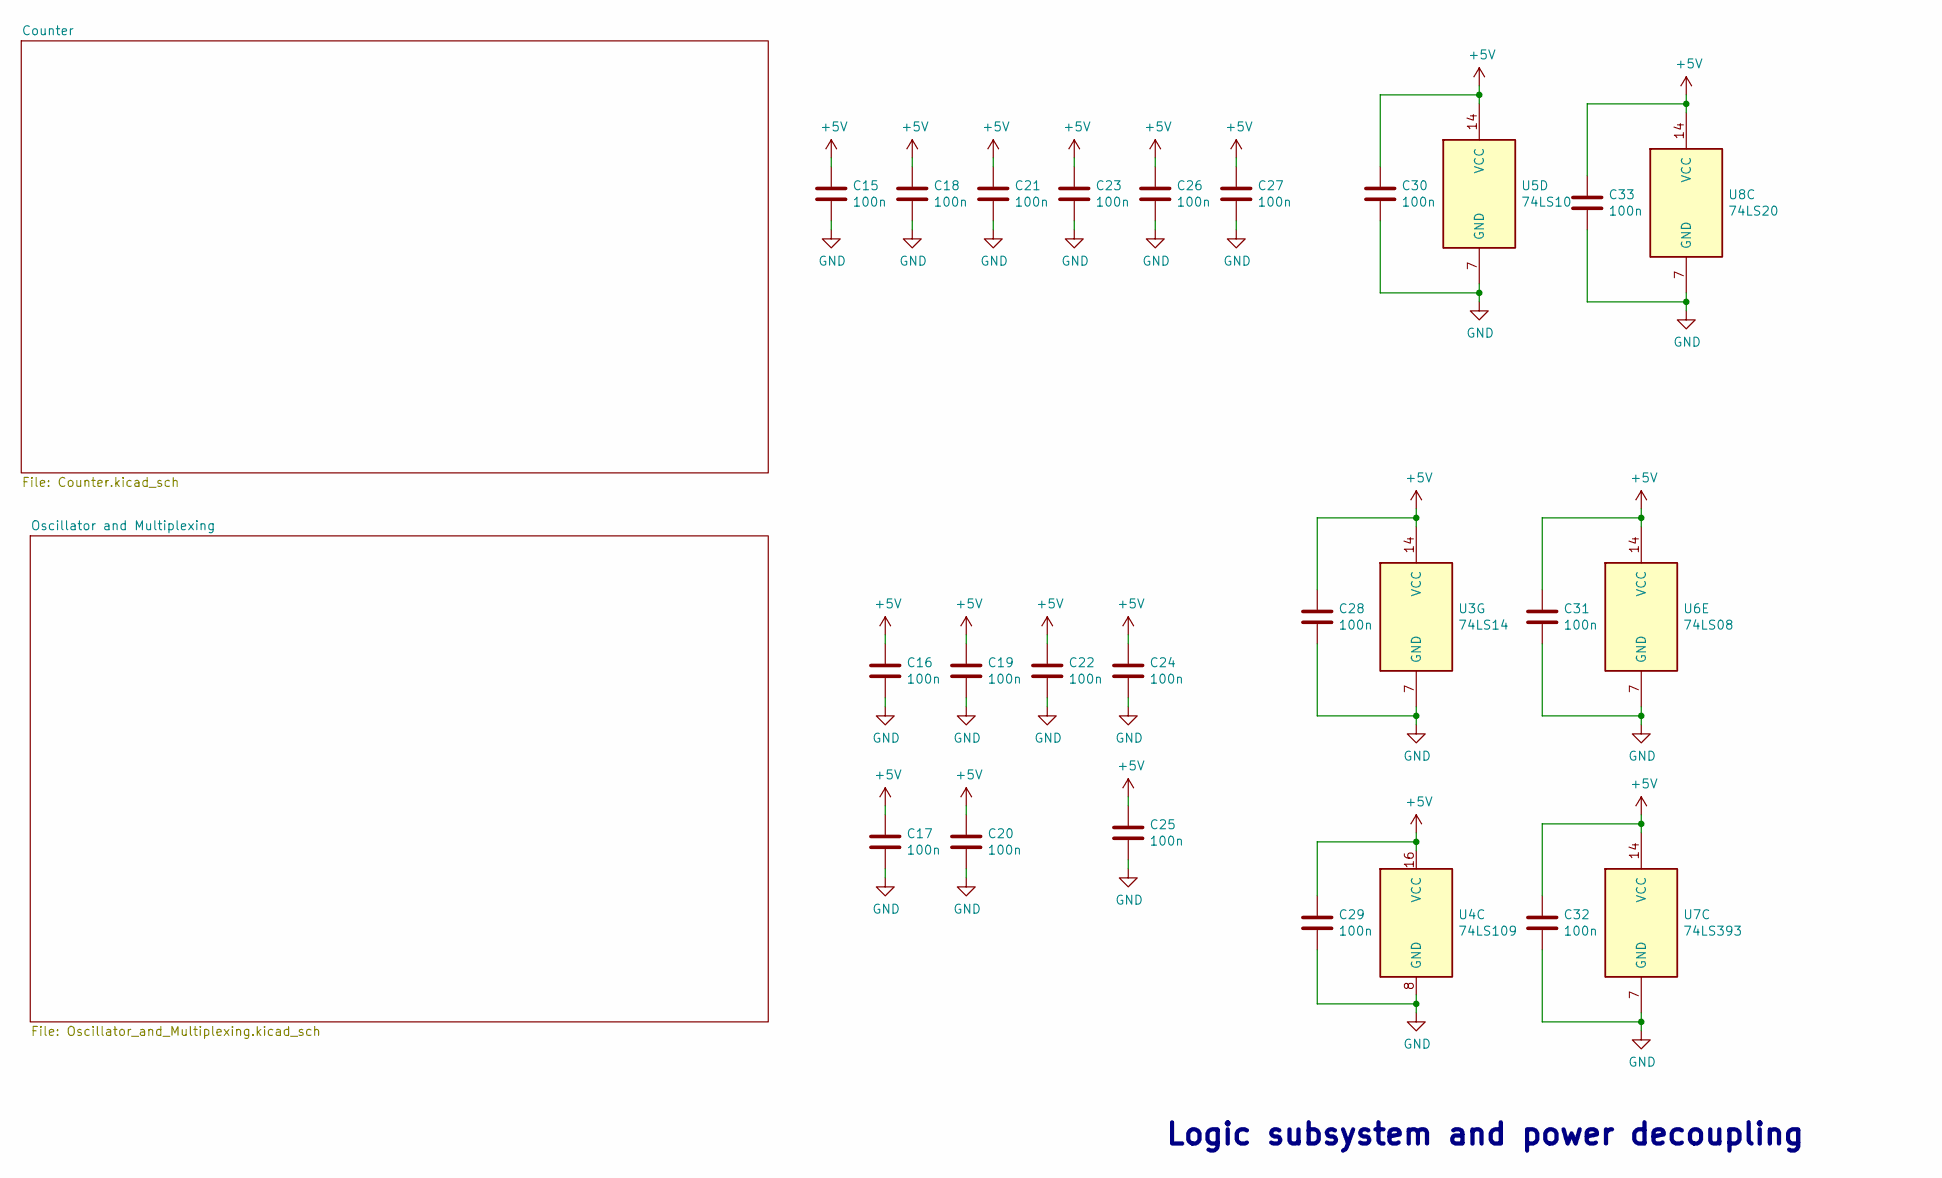
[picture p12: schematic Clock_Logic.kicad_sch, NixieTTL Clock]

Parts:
C15, C16, C17, C18, C19, C20, C21, C22, C23, C24, C25, C26, C27, C28, C29, C30, C31, C32, C33: 100n; C_Rect_L7.0mm_W2.5mm_P5.00mm
U3: 74LS14; DIP-14_W7.62mm
U4: 74LS109; DIP-16_W7.62mm
U5: 74LS10; DIP-14_W7.62mm
U6: 74LS08; DIP-14_W7.62mm
U7: 74LS393; DIP-14_W7.62mm
U8: 74LS20; DIP-14_W7.62mm

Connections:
+5V: C15.1, C16.1, C17.1, C18.1, C19.1, C20.1, C21.1, C22.1, C23.1, C24.1, C25.1, C26.1, C27.1, C28.1, C29.1, C30.1, C31.1, C32.1, C33.1, U3.14 (VCC), U4.16 (VCC), U5.14 (VCC), U6.14 (VCC), U7.14 (VCC), U8.14 (VCC); also elsewhere on the board
GND: C15.2, C16.2, C17.2, C18.2, C19.2, C20.2, C21.2, C22.2, C23.2, C24.2, C25.2, C26.2, C27.2, C28.2, C29.2, C30.2, C31.2, C32.2, C33.2, U3.7 (GND), U4.8 (GND), U5.7 (GND), U6.7 (GND), U7.7 (GND), U8.7 (GND); also elsewhere on the board

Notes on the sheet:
Logic subsystem and power decoupling

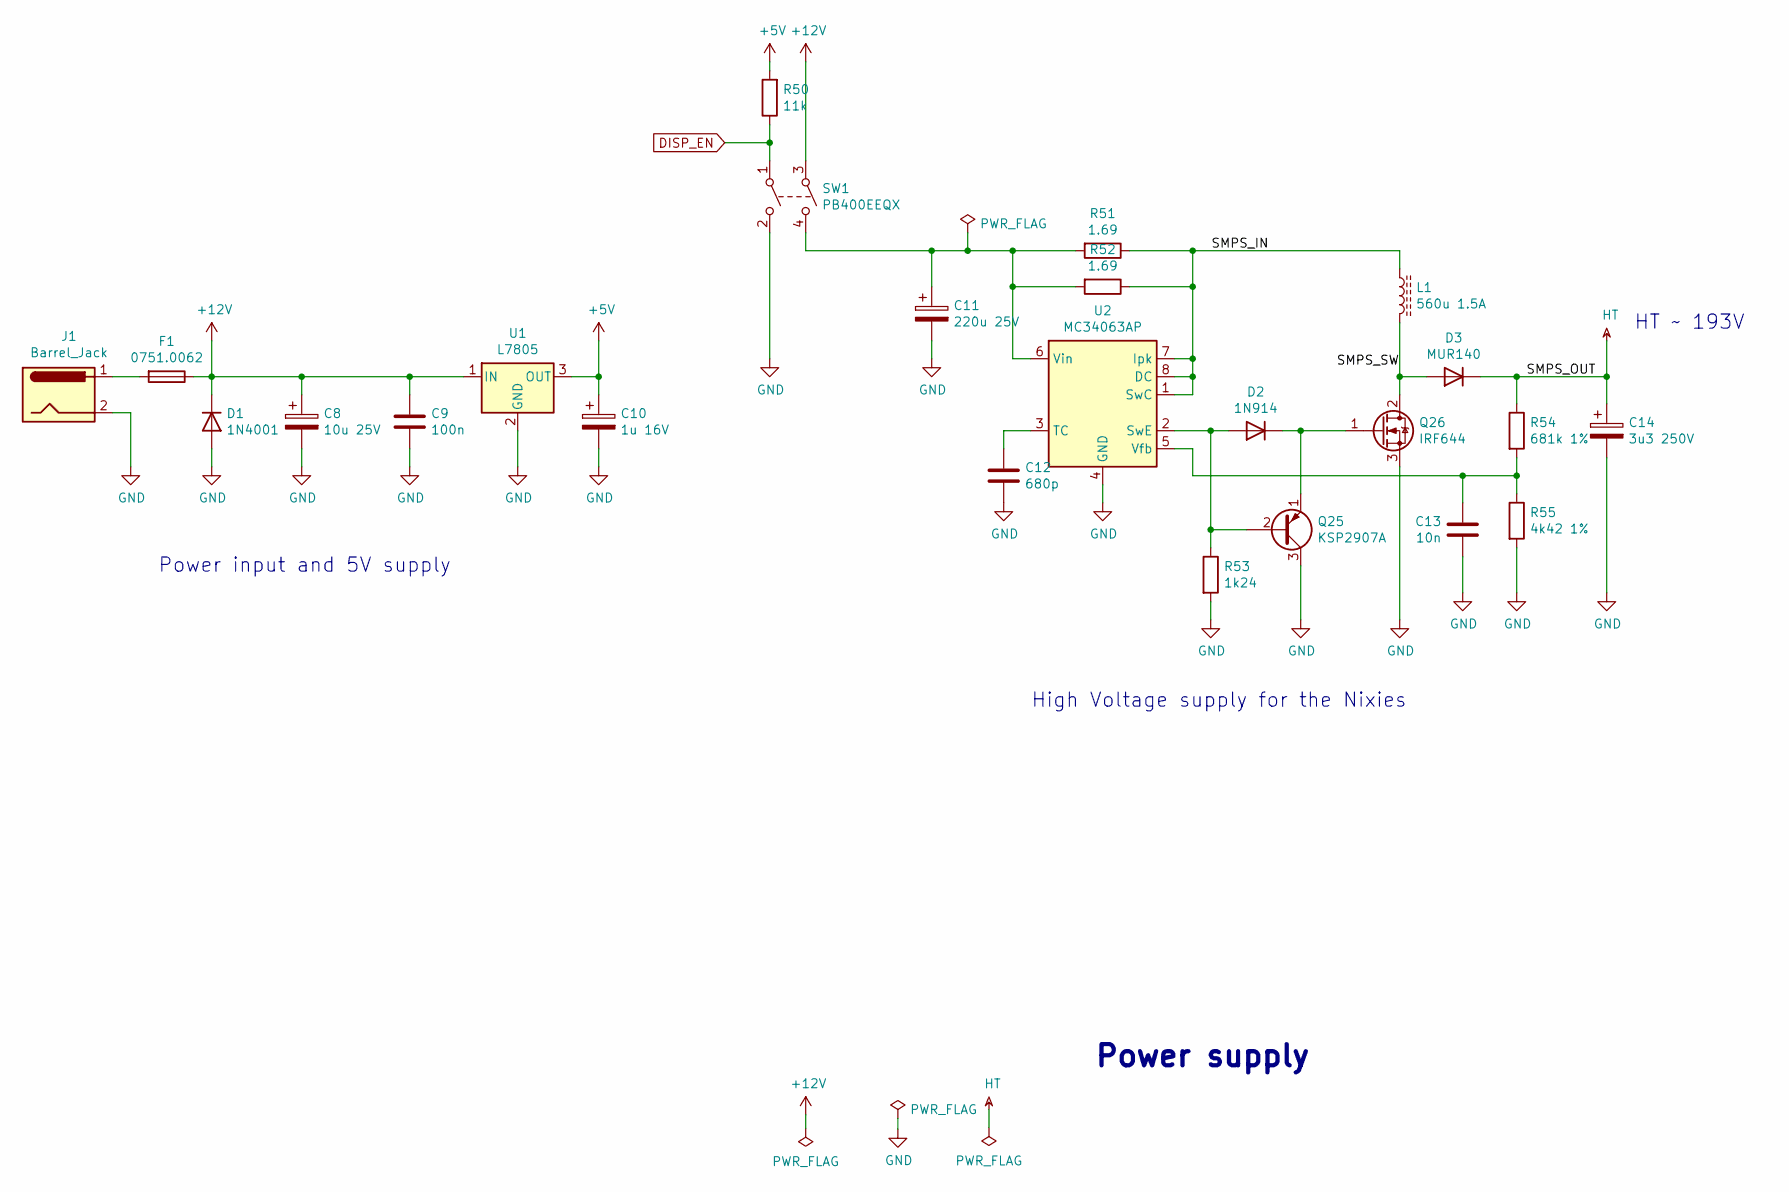
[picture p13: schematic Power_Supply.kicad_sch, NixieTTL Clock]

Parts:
C8: 10u 25V; CP_Radial_D5.0mm_P2.50mm
C9: 100n; C_Rect_L7.0mm_W2.5mm_P5.00mm
C10: 1u 16V; CP_Radial_D5.0mm_P2.50mm
C11: 220u 25V; CP_Radial_D8.0mm_P3.80mm
C12: 680p; C_Rect_L7.0mm_W4.5mm_P5.00mm
C13: 10n; C_Rect_L7.0mm_W2.5mm_P5.00mm
C14: 3u3 250V; CP_Radial_D8.0mm_P3.80mm
D1: 1N4001; D_DO-41_SOD81_P10.16mm_Horizontal
D2: 1N914; D_DO-35_SOD27_P7.62mm_Horizontal
D3: MUR140; D_DO-41_SOD81_P7.62mm_Horizontal
F1: 0751.0062; 5x20 fuse
J1: Barrel_Jack; BarrelJack_Horizontal
L1: 560u 1.5A; L_Radial_D12.0mm_P6.00mm_MuRATA_1900R
Q25: KSP2907A; TO-92_Inline_Wide
Q26: IRF644; TO-220-3_Vertical
R50: 11k; R_Axial_DIN0207_L6.3mm_D2.5mm_P10.16mm_Horizontal
R51, R52: 1.69; R_Axial_DIN0207_L6.3mm_D2.5mm_P10.16mm_Horizontal
R53: 1k24; R_Axial_DIN0207_L6.3mm_D2.5mm_P10.16mm_Horizontal
R54: 681k 1%; R_Axial_DIN0207_L6.3mm_D2.5mm_P10.16mm_Horizontal
R55: 4k42 1%; R_Axial_DIN0207_L6.3mm_D2.5mm_P10.16mm_Horizontal
SW1: PB400EEQX
U1: L7805; TO-220-3_Vertical
U2: MC34063AP; DIP-8_W7.62mm

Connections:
+5V: C10.1, R50.2, U1.3 (OUT); also elsewhere on the board
+12V: C8.1, C9.1, D1.1 (K), F1.1, SW1.3, U1.1 (IN)
/Power Supply/SMPS_IN: L1.1, R51.1, R52.1, U2.1 (SwC), U2.7 (Ipk), U2.8 (DC)
/Power Supply/SMPS_SW: D3.2 (A), L1.2, Q26.2 (D)
DISP_EN: R50.1, SW1.1; also elsewhere on the board
GND: C8.2, C9.2, C10.2, C11.2, C12.2, C13.2, C14.2, D1.2 (A), J1.2, Q25.3 (C), Q26.3 (S), R53.2, R55.2, SW1.2, U1.2 (GND), U2.4 (GND); also elsewhere on the board
HT: C14.1, D3.1 (K), R54.1; also elsewhere on the board
unnamed: C11.1, R51.2, R52.2, SW1.4, U2.6 (Vin)
unnamed: C12.1, U2.3 (TC)
unnamed: C13.1, R54.2, R55.1, U2.5 (Vfb)
unnamed: D2.1 (K), Q25.1 (E), Q26.1 (G)
unnamed: D2.2 (A), Q25.2 (B), R53.1, U2.2 (SwE)
unnamed: F1.2, J1.1

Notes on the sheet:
Power supply
Power input and 5V supply
High Voltage supply for the Nixies
HT ~ 193V

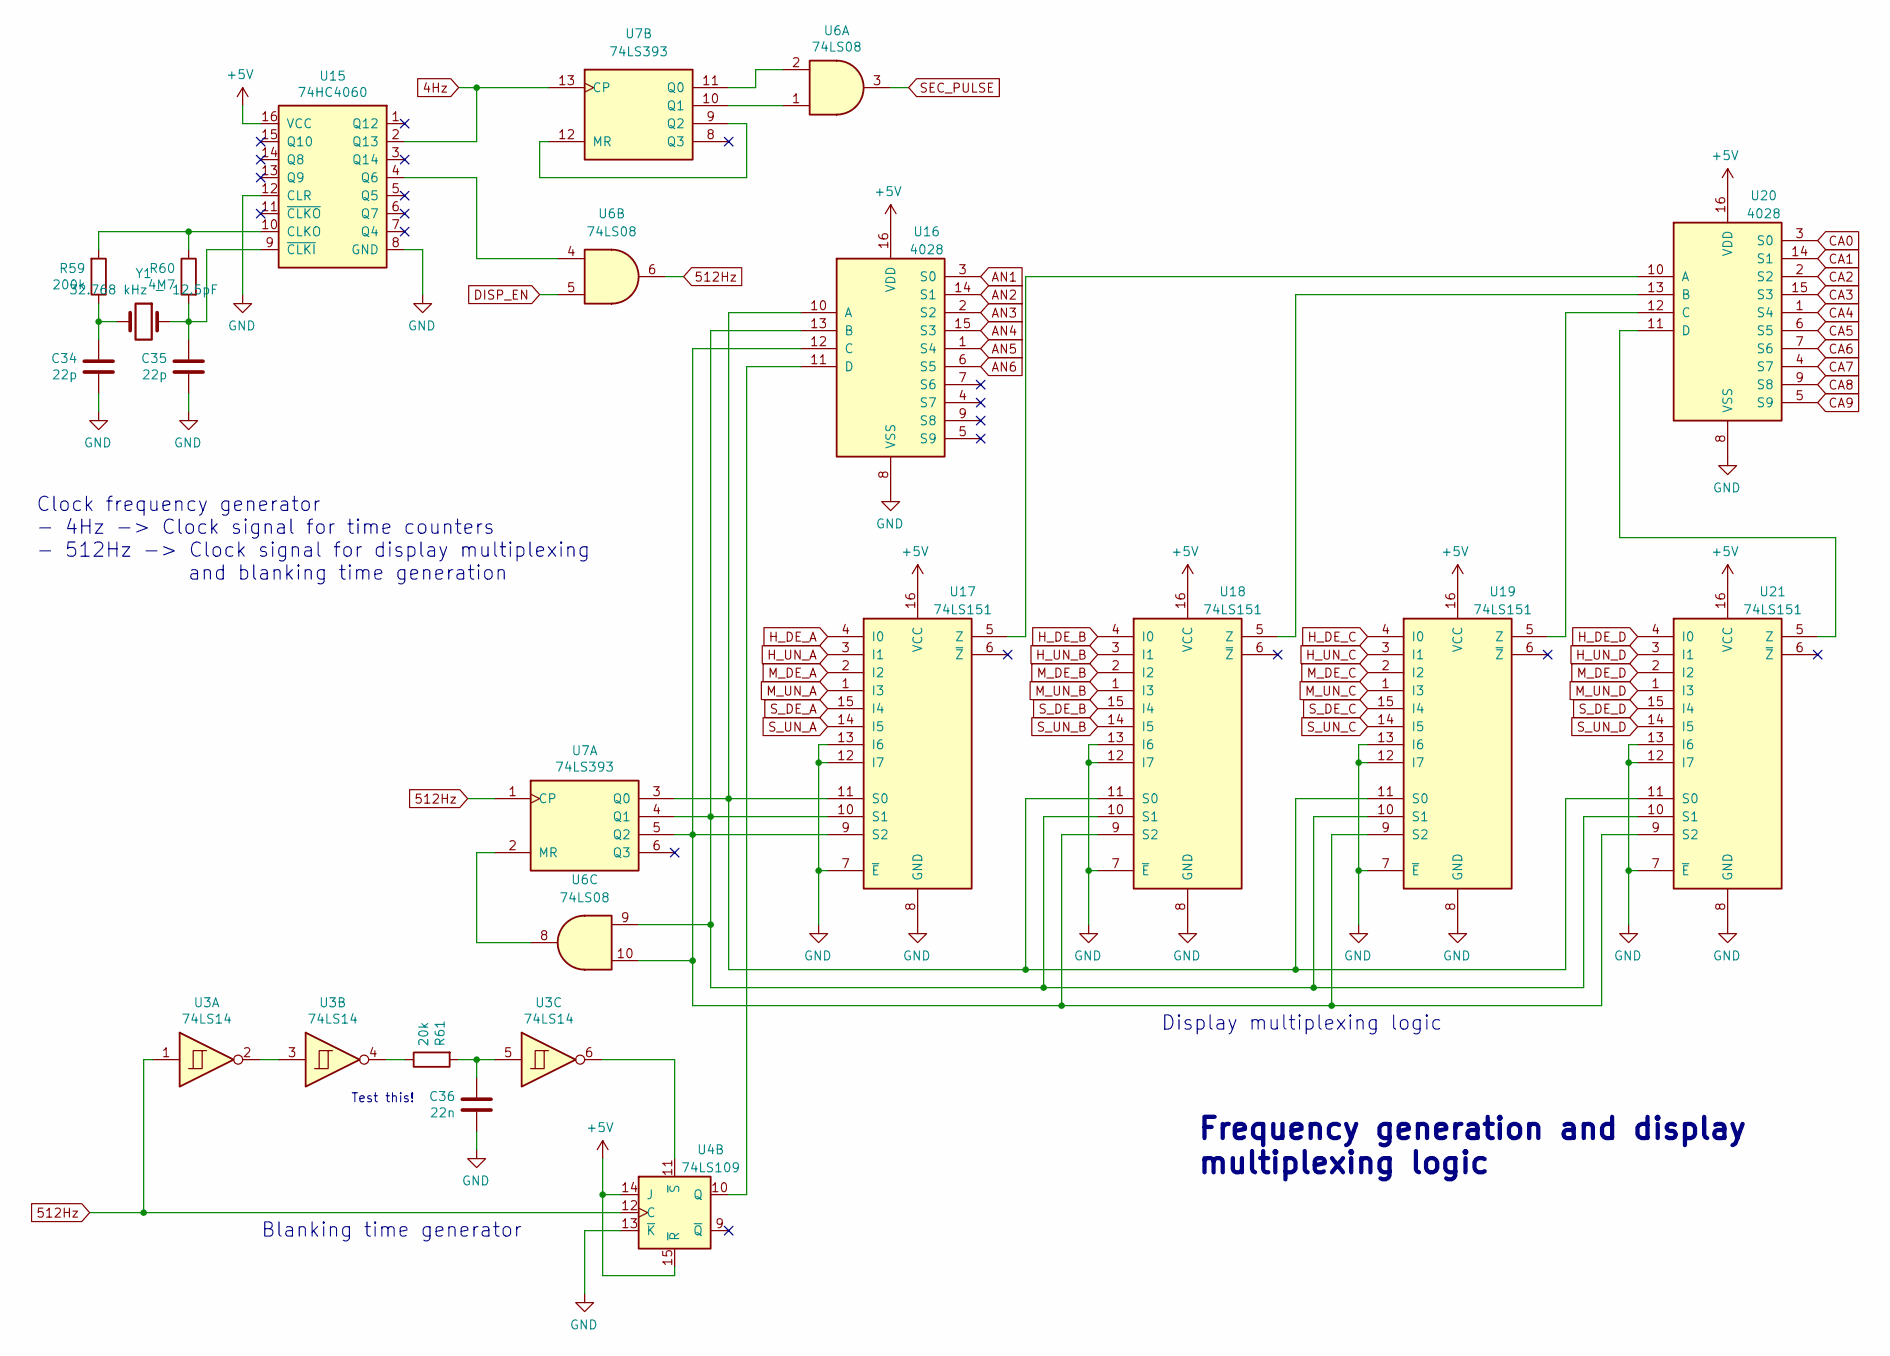
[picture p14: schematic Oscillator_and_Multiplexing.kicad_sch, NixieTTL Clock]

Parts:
C34, C35: 22p; C_Disc_D5.1mm_W3.2mm_P5.00mm
C36: 22n; C_Rect_L7.0mm_W2.5mm_P5.00mm
R59: 200k; R_Axial_DIN0207_L6.3mm_D2.5mm_P10.16mm_Horizontal
R60: 4M7; R_Axial_DIN0207_L6.3mm_D2.5mm_P10.16mm_Horizontal
R61: 20k; R_Axial_DIN0207_L6.3mm_D2.5mm_P10.16mm_Horizontal
U3: 74LS14; DIP-14_W7.62mm
U4: 74LS109; DIP-16_W7.62mm
U6: 74LS08; DIP-14_W7.62mm
U7: 74LS393; DIP-14_W7.62mm
U15: 74HC4060; DIP-16_W7.62mm
U16, U20: 4028; DIP-16_W7.62mm
U17, U18, U19, U21: 74LS151; DIP-16_W7.62mm
Y1: 32.768 kHz - 12.5pF; Crystal_C38-LF_D3.0mm_L8.0mm_Vertical

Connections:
4Hz: U7.13 (CP), U15.2 (Q13); also elsewhere on the board
512Hz: U3.1, U4.12 (C), U6.6, U7.1 (CP)
+5V: U4.14 (J), U4.15 (~R), U15.16 (VCC), U16.16 (VDD), U17.16 (VCC), U18.16 (VCC), U19.16 (VCC), U20.16 (VDD), U21.16 (VCC); also elsewhere on the board
AN1: U16.3 (S0); also elsewhere on the board
AN2: U16.14 (S1); also elsewhere on the board
AN3: U16.2 (S2); also elsewhere on the board
AN4: U16.15 (S3); also elsewhere on the board
AN5: U16.1 (S4); also elsewhere on the board
AN6: U16.6 (S5); also elsewhere on the board
CA0: U20.3 (S0); also elsewhere on the board
CA1: U20.14 (S1); also elsewhere on the board
CA2: U20.2 (S2); also elsewhere on the board
CA3: U20.15 (S3); also elsewhere on the board
CA4: U20.1 (S4); also elsewhere on the board
CA5: U20.6 (S5); also elsewhere on the board
CA6: U20.7 (S6); also elsewhere on the board
CA7: U20.4 (S7); also elsewhere on the board
CA8: U20.9 (S8); also elsewhere on the board
CA9: U20.5 (S9); also elsewhere on the board
DISP_EN: U6.5; also elsewhere on the board
GND: C34.2, C35.2, C36.2, U4.13 (~K), U15.8 (GND), U15.12 (CLR), U16.8 (VSS), U17.7 (~E), U17.8 (GND), U17.12 (I7), U17.13 (I6), U18.7 (~E), U18.8 (GND), U18.12 (I7), U18.13 (I6), U19.7 (~E), U19.8 (GND), U19.12 (I7), U19.13 (I6), U20.8 (VSS), U21.7 (~E), U21.8 (GND), U21.12 (I7), U21.13 (I6); also elsewhere on the board
H_DE_A: U17.4 (I0); also elsewhere on the board
H_DE_B: U18.4 (I0); also elsewhere on the board
H_DE_C: U19.4 (I0); also elsewhere on the board
H_DE_D: U21.4 (I0); also elsewhere on the board
H_UN_A: U17.3 (I1); also elsewhere on the board
H_UN_B: U18.3 (I1); also elsewhere on the board
H_UN_C: U19.3 (I1); also elsewhere on the board
H_UN_D: U21.3 (I1); also elsewhere on the board
M_DE_A: U17.2 (I2); also elsewhere on the board
M_DE_B: U18.2 (I2); also elsewhere on the board
M_DE_C: U19.2 (I2); also elsewhere on the board
M_DE_D: U21.2 (I2); also elsewhere on the board
M_UN_A: U17.1 (I3); also elsewhere on the board
M_UN_B: U18.1 (I3); also elsewhere on the board
M_UN_C: U19.1 (I3); also elsewhere on the board
M_UN_D: U21.1 (I3); also elsewhere on the board
unnamed: C34.1, R59.1, Y1.2
unnamed: C35.1, R60.2, U15.9 (~CLKI), Y1.1
unnamed: C36.1, R61.2, U3.5
unnamed: R59.2, R60.1, U15.10 (CLKO)
unnamed: R61.1, U3.4
unnamed: U3.2, U3.3
unnamed: U3.6, U4.11 (~S)
unnamed: U6.1, U7.10 (Q1)
unnamed: U6.2, U7.11 (Q0)
unnamed: U6.8, U7.2 (MR)
unnamed: U7.9 (Q2), U7.12 (MR)
unnamed: U6.4, U15.4 (Q6)
unnamed: U7.3 (Q0), U16.10 (A), U17.11 (S0), U18.11 (S0), U19.11 (S0), U21.11 (S0)
unnamed: U4.10 (Q), U16.11 (D)
unnamed: U6.10, U7.5 (Q2), U16.12 (C), U17.9 (S2), U18.9 (S2), U19.9 (S2), U21.9 (S2)
unnamed: U6.9, U7.4 (Q1), U16.13 (B), U17.10 (S1), U18.10 (S1), U19.10 (S1), U21.10 (S1)
unnamed: U17.5 (Z), U20.10 (A)
unnamed: U18.5 (Z), U20.13 (B)
unnamed: U19.5 (Z), U20.12 (C)
unnamed: U20.11 (D), U21.5 (Z)
SEC_PULSE: U6.3; also elsewhere on the board
S_DE_A: U17.15 (I4); also elsewhere on the board
S_DE_B: U18.15 (I4); also elsewhere on the board
S_DE_C: U19.15 (I4); also elsewhere on the board
S_DE_D: U21.15 (I4); also elsewhere on the board
S_UN_A: U17.14 (I5); also elsewhere on the board
S_UN_B: U18.14 (I5); also elsewhere on the board
S_UN_C: U19.14 (I5); also elsewhere on the board
S_UN_D: U21.14 (I5); also elsewhere on the board

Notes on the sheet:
Clock frequency generator - 4Hz -> Clock signal for time counters - 512Hz -> Clock signal for display multiplexing and blanking time generation
Display multiplexing logic
Test this!
Blanking time generator
Frequency generation and display multiplexing logic

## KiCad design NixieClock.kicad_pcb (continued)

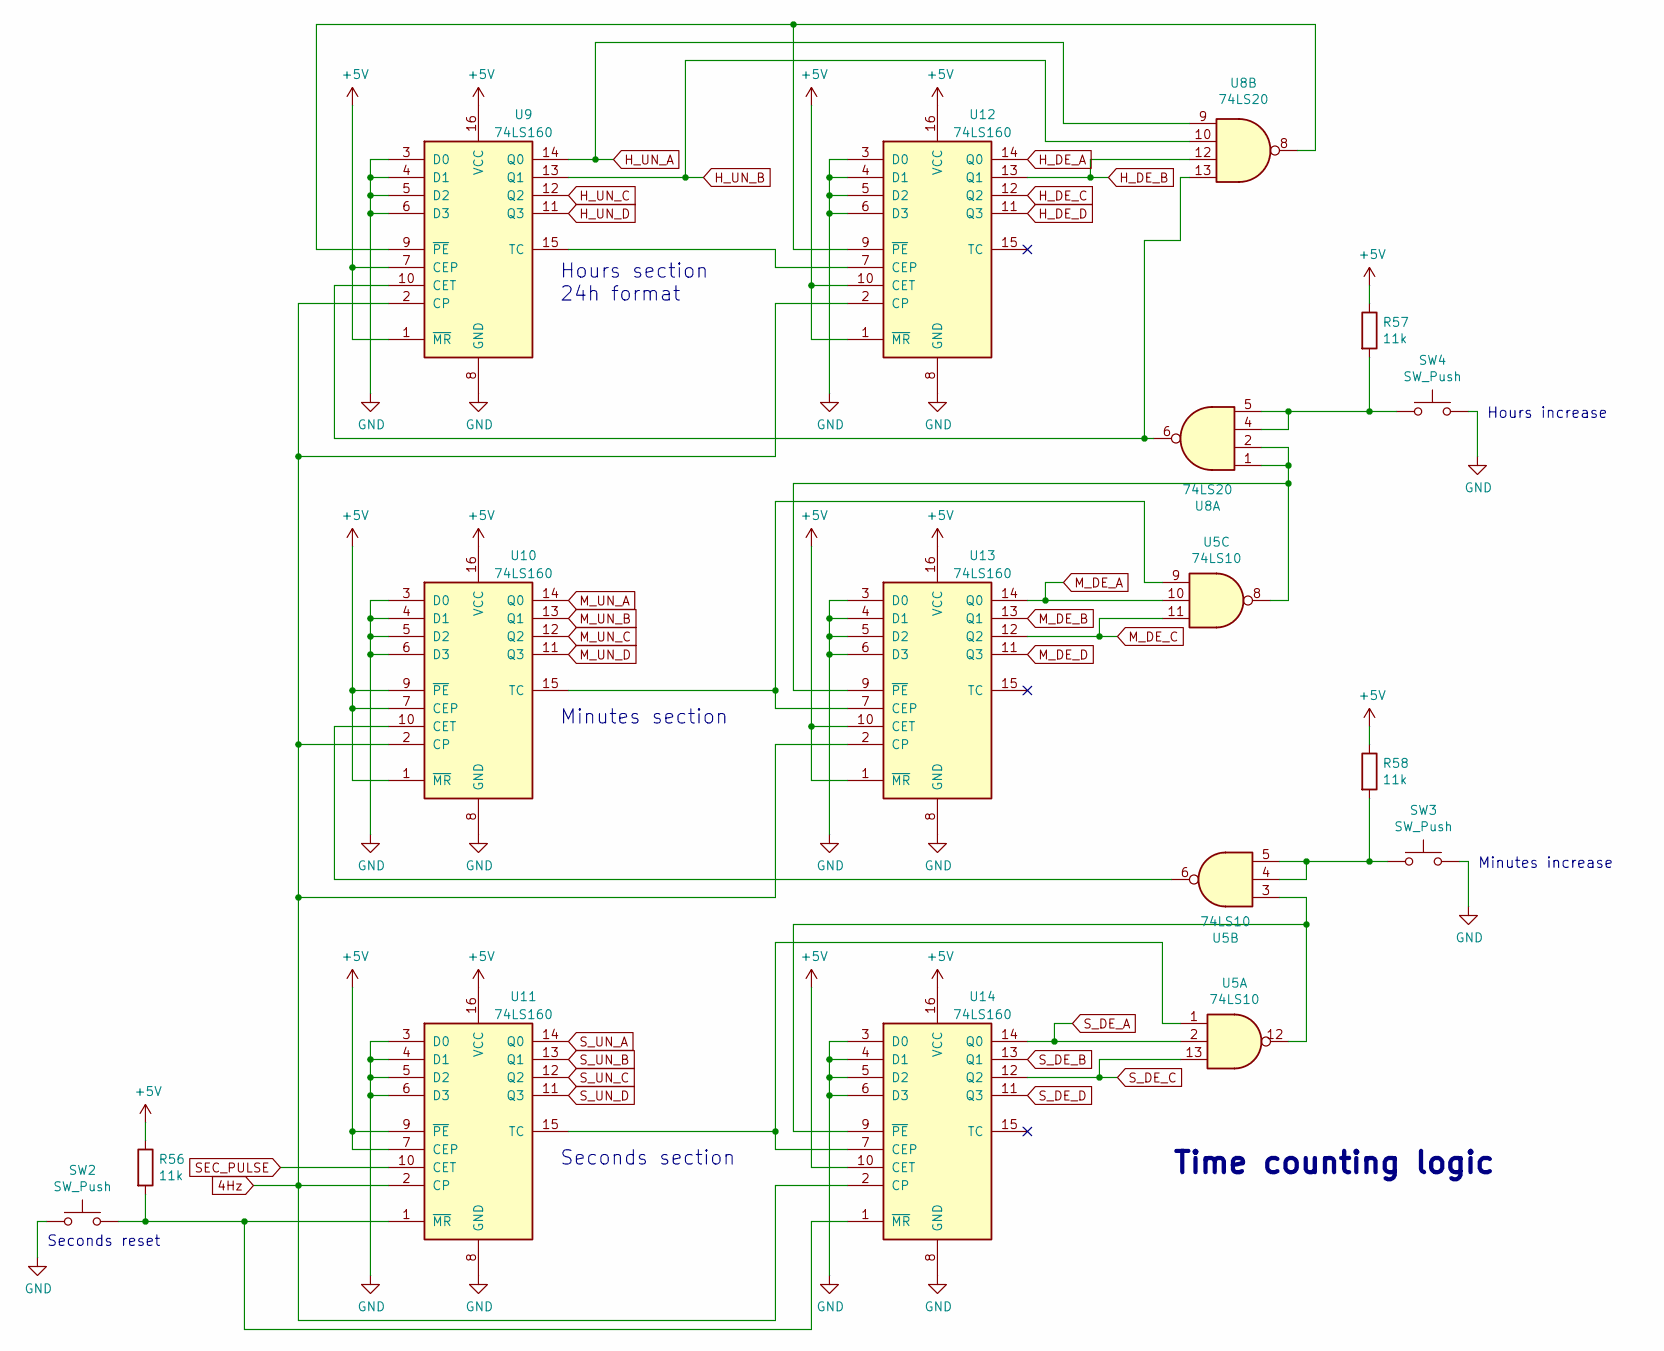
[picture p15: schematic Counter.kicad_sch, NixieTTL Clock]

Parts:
R56, R57, R58: 11k; R_Axial_DIN0207_L6.3mm_D2.5mm_P10.16mm_Horizontal
SW2, SW3, SW4: SW_Push; SW_Tactile_SPST_Angled_PTS645Vx83-2LFS
U5: 74LS10; DIP-14_W7.62mm
U8: 74LS20; DIP-14_W7.62mm
U9, U10, U11, U12, U13, U14: 74LS160; DIP-16_W7.62mm

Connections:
4Hz: U9.2 (CP), U10.2 (CP), U11.2 (CP), U12.2 (CP), U13.2 (CP), U14.2 (CP); also elsewhere on the board
+5V: R56.1, R57.1, R58.1, U9.1 (~MR), U9.7 (CEP), U9.16 (VCC), U10.1 (~MR), U10.7 (CEP), U10.9 (~PE), U10.16 (VCC), U11.7 (CEP), U11.9 (~PE), U11.16 (VCC), U12.1 (~MR), U12.10 (CET), U12.16 (VCC), U13.1 (~MR), U13.10 (CET), U13.16 (VCC), U14.10 (CET), U14.16 (VCC); also elsewhere on the board
GND: SW2.1, SW3.2, SW4.2, U9.3 (D0), U9.4 (D1), U9.5 (D2), U9.6 (D3), U9.8 (GND), U10.3 (D0), U10.4 (D1), U10.5 (D2), U10.6 (D3), U10.8 (GND), U11.3 (D0), U11.4 (D1), U11.5 (D2), U11.6 (D3), U11.8 (GND), U12.3 (D0), U12.4 (D1), U12.5 (D2), U12.6 (D3), U12.8 (GND), U13.3 (D0), U13.4 (D1), U13.5 (D2), U13.6 (D3), U13.8 (GND), U14.3 (D0), U14.4 (D1), U14.5 (D2), U14.6 (D3), U14.8 (GND); also elsewhere on the board
H_DE_A: U12.14 (Q0); also elsewhere on the board
H_DE_B: U8.12, U12.13 (Q1); also elsewhere on the board
H_DE_C: U12.12 (Q2); also elsewhere on the board
H_DE_D: U12.11 (Q3); also elsewhere on the board
H_UN_A: U8.9, U9.14 (Q0); also elsewhere on the board
H_UN_B: U8.10, U9.13 (Q1); also elsewhere on the board
H_UN_C: U9.12 (Q2); also elsewhere on the board
H_UN_D: U9.11 (Q3); also elsewhere on the board
M_DE_A: U5.10, U13.14 (Q0); also elsewhere on the board
M_DE_B: U13.13 (Q1); also elsewhere on the board
M_DE_C: U5.11, U13.12 (Q2); also elsewhere on the board
M_DE_D: U13.11 (Q3); also elsewhere on the board
M_UN_A: U10.14 (Q0); also elsewhere on the board
M_UN_B: U10.13 (Q1); also elsewhere on the board
M_UN_C: U10.12 (Q2); also elsewhere on the board
M_UN_D: U10.11 (Q3); also elsewhere on the board
unnamed: R56.2, SW2.2, U11.1 (~MR), U14.1 (~MR)
unnamed: R57.2, SW4.1, U8.4, U8.5
unnamed: R58.2, SW3.1, U5.4, U5.5
unnamed: U8.6, U8.13, U9.10 (CET)
unnamed: U5.6, U10.10 (CET)
unnamed: U5.9, U10.15 (TC), U13.7 (CEP)
unnamed: U5.1, U11.15 (TC), U14.7 (CEP)
unnamed: U9.15 (TC), U12.7 (CEP)
unnamed: U8.8, U9.9 (~PE), U12.9 (~PE)
unnamed: U5.8, U8.1, U8.2, U13.9 (~PE)
unnamed: U5.3, U5.12, U14.9 (~PE)
SEC_PULSE: U11.10 (CET); also elsewhere on the board
S_DE_A: U5.2, U14.14 (Q0); also elsewhere on the board
S_DE_B: U14.13 (Q1); also elsewhere on the board
S_DE_C: U5.13, U14.12 (Q2); also elsewhere on the board
S_DE_D: U14.11 (Q3); also elsewhere on the board
S_UN_A: U11.14 (Q0); also elsewhere on the board
S_UN_B: U11.13 (Q1); also elsewhere on the board
S_UN_C: U11.12 (Q2); also elsewhere on the board
S_UN_D: U11.11 (Q3); also elsewhere on the board

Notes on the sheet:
Time counting logic
Seconds reset
Hours increase
Minutes section
Hours section 24h format
Minutes increase
Seconds section

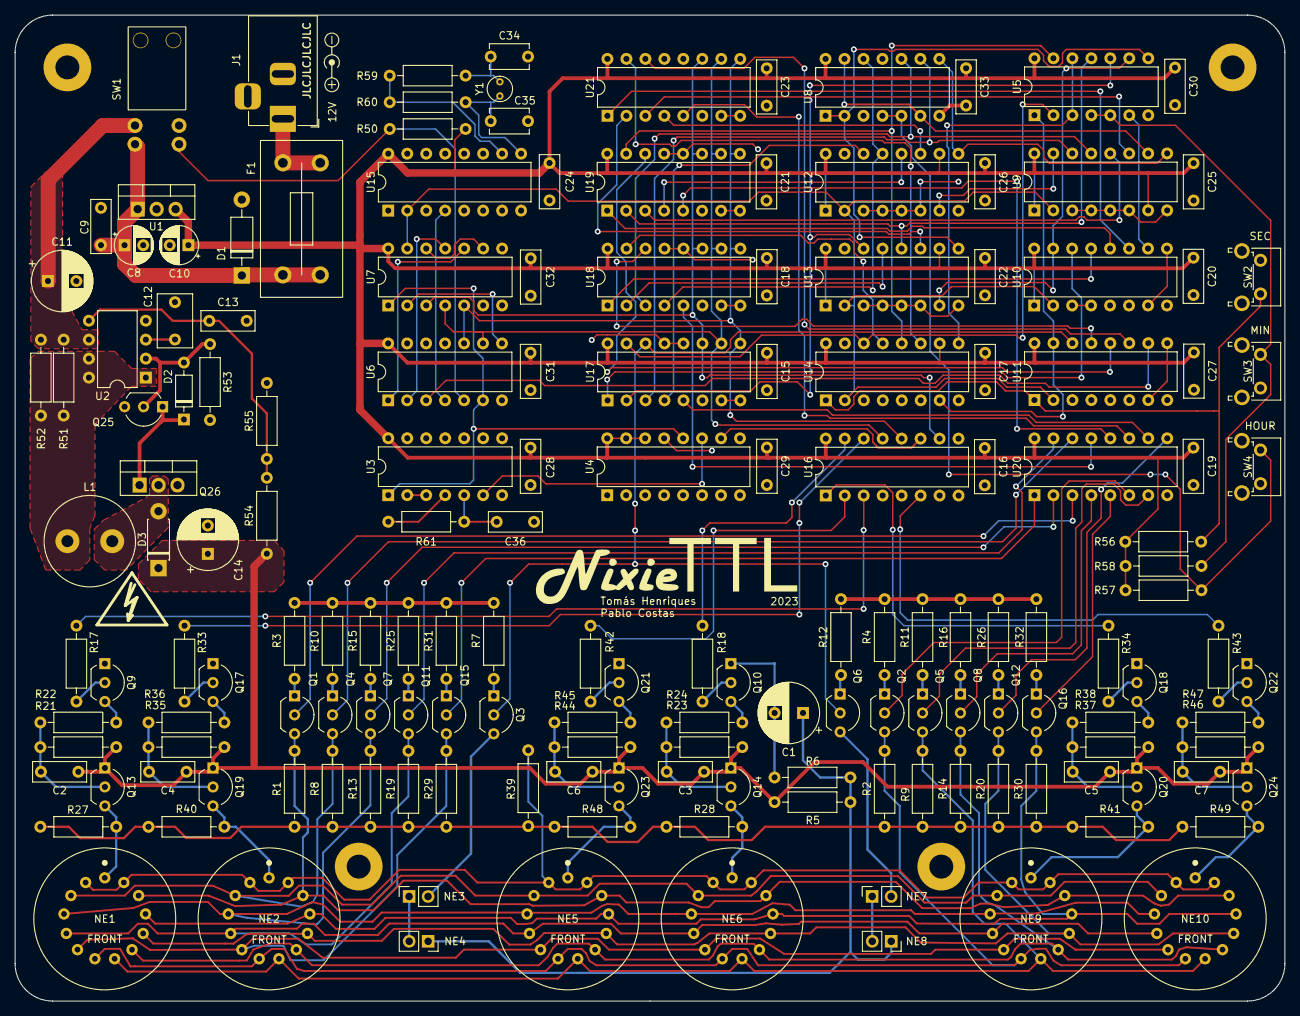
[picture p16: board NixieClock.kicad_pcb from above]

Board: 2 copper layers, 170.0 x 132.0 mm, 166 parts (0 on the bottom side), 140 nets.

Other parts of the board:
12V: Symbol_Barrel_Polarity

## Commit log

2021-01-14 Upload original design idea
    [BOM.xlsx, Clock_Logic.sch, Counter.sch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]
2022-02-25 Design moved to KiCad 6, counter logic fixed, extra display connector removed
    [BOM.xlsx, Clock_Logic.kicad_sch, Clock_Logic.sch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]
2023-03-04 layout started
    [Clock_Logic.kicad_sch, Counter.kicad_sch, Display_Driver.kicad_sch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]
2023-04-01 Layout completed
    [NixieClock.kicad_pcb, Power_Supply.kicad_sch]
2023-04-15 Implemented changes from pablo_cambios branch. Generated Gerbers
    [Clock_Logic.kicad_sch, Counter.kicad_sch, Display_Driver.kicad_sch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]
